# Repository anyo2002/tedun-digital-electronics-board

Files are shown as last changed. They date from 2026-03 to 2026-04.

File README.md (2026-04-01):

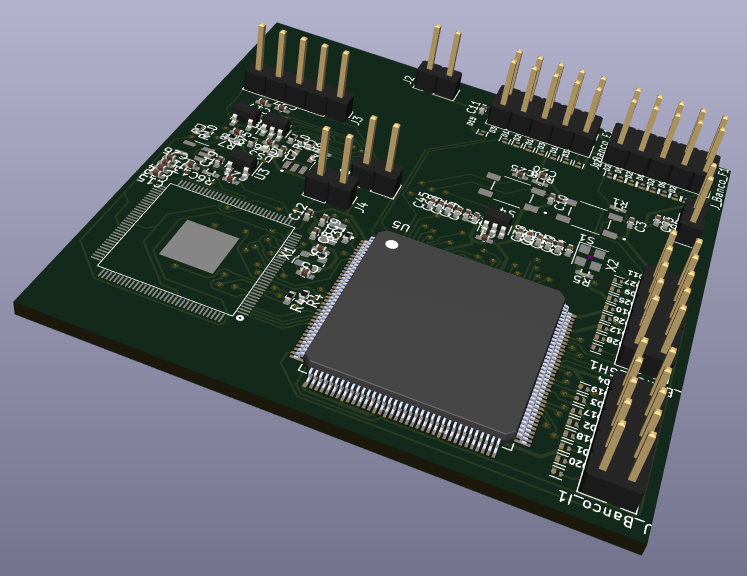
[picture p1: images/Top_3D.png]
Top 3D


# TEDUN - Digital Electronics Development Board

## 📌 Overview
The **TEDUN (Tarjeta de Electrónica Digital de la UNAL)** is an academic project developed as part of an Embedded Systems course in Electronic Engineering.

> ⚠️ Note: The project name does not represent an official product of UNAL. It only reflects the academic context in which it was developed.

This project consists of the design and implementation of a **custom development board** based on:
- A **F133A RISC-V processor**
- A **Trion T8Q144C3 FPGA**

The board enables hardware experimentation with multiple modules (Bluetooth, audio, infrared, etc.) using communication protocols such as **UART, I2S, SPI**, and **GPIO**.

---

## 🎯 Objectives
- Design a complete embedded development board
- Enable communication between a processor and an FPGA
- Support hardware testing using multiple digital interfaces
- Develop schematics and PCB using KiCad
- Implement FPGA programming using open-source tools

---

## ⚙️ Key Features

- Powered via **Micro-USB (~5V)**
- Boot via **SD card with Tina Linux**
- UART communication with a computer (via USB-UART converter)
- FPGA programming using **OpenOCD (JTAG)**
- Communication between F133A and FPGA via **UART or SPI**
- 32 GPIO pins organized in **4 banks (3.3V + 5V output)**

---

## 🏗️ System Architecture

The system integrates:
- F133A processor (RISC-V)
- Trion T8 FPGA
- SD card storage
- Multiple communication interfaces

### Interfaces

#### 🔹 JTAG
Used to program the FPGA through OpenOCD running on the F133A.

#### 🔹 SD Card
Stores:
- Tina Linux OS
- Boot partitions
- Drivers and applications
- FPGA configuration files

#### 🔹 UART & I2S
- UART for communication with PC and FPGA
- I2S for audio/data transmission

#### 🔹 GPIO
- 32 configurable pins
- Used for hardware testing and module integration

---

## 🧩 Block Diagram

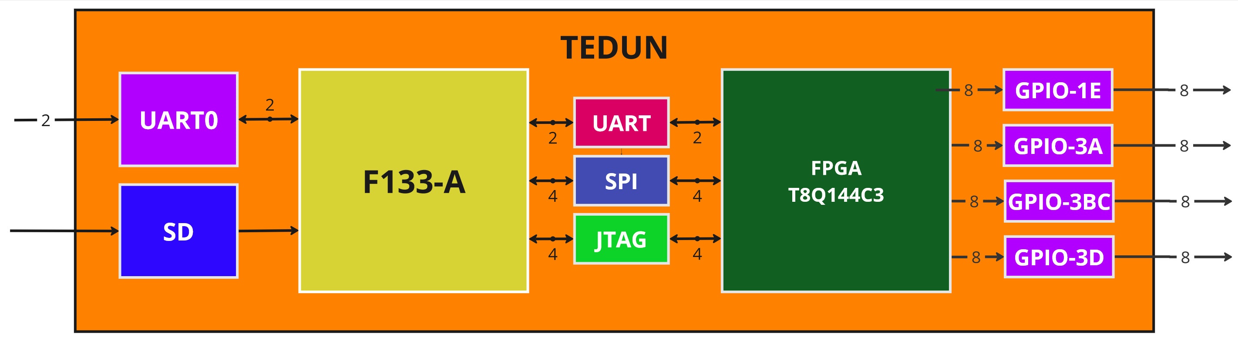
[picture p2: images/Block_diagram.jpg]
Block Diagram


---

## 🔌 Interface Design

To validate the system, an **LctechPi board (F133A-based)** was used for testing.

Key points:
- Tina Linux was configured and deployed
- Required system packages were installed
- WiFi was tested but not included (cost optimization)

### Tool Selection

Two tools were evaluated:

#### ❌ openFPGALoader
- Supports Trion FPGA
- Limited to memory-based programming (Flash)
- ❌ Not suitable for JTAG-based programming via F133A

#### ✅ OpenOCD
- Open-source
- Supports JTAG
- Compatible with Trion FPGA
- ✔️ Selected solution

---

## 🧪 FPGA Programming with OpenOCD

OpenOCD was compiled for RISC-V and deployed on the board.

### Setup Steps:
1. Compile OpenOCD from source:
   https://github.com/riscv/riscv-openocd

2. Copy binary to:
/bin/

3. Copy scripts to:
/usr/local/share/openocd/scripts

4. Create configuration file:
openocd.cfg

### Example Configuration (JTAG via GPIO)

```bash
adapter driver sysfsgpio
transport select jtag
sysfsgpio jtag_nums 2 3 1 4

set CHIPNAME fpga_trion
source [find fpga/efinix_trion.cfg]

init
pld load fpga_trion.pld GPIO_demo.bit
```

## 🛠️ Hardware Design

The hardware design is based on:

- MangoPi (F133A reference)

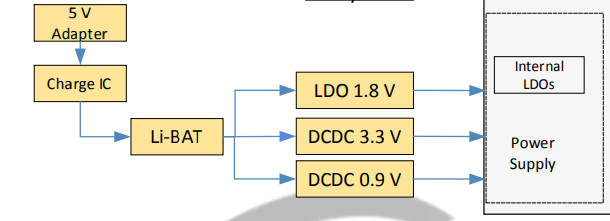
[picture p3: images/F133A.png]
Power Supply


- LctechPi board

- Trion T8 FPGA reference boards

## 🔋 Power Supply

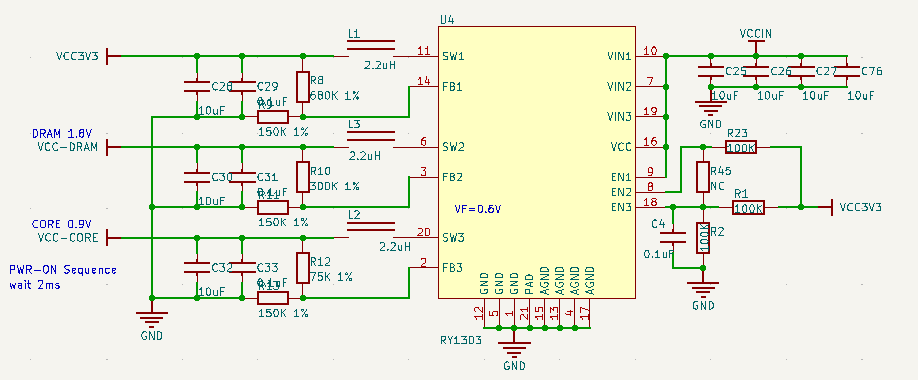
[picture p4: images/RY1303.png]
RY1303


- Input: Micro-USB (5V)
- Regulation using:
  - AMS1117 (instead of RY1303 from the MangoPi board)
  - Multiple LDO regulators

## Voltage Levels:
- 3.3V → I/O, GPIO, oscillator

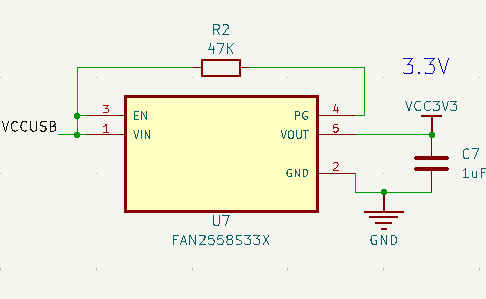
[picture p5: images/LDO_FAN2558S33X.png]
FAN2558S33X


- 1.8V → DRAM

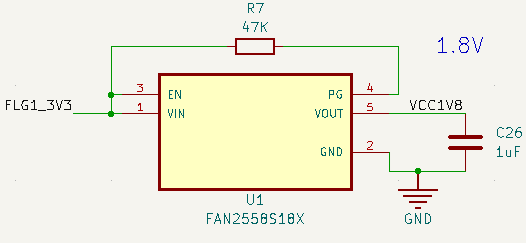
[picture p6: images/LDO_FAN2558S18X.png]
FAN2558S18X


- 2.8V → Communication block (PE)

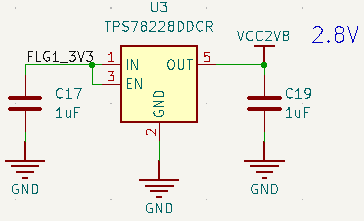
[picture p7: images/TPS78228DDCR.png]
TPS78228DDCR


- 1.2V → FPGA core

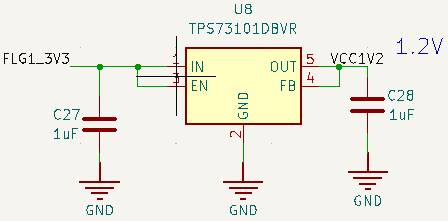
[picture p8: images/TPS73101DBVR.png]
TPS73101DBVR


- 0.9V → Processor core

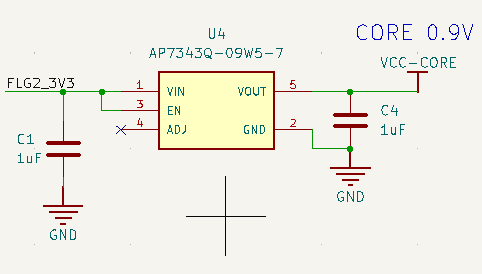
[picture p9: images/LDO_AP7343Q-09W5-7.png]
AP7343Q-09W5-7


## ⚡ Power Sequencing

Implemented using:
- LM3880 power sequencer

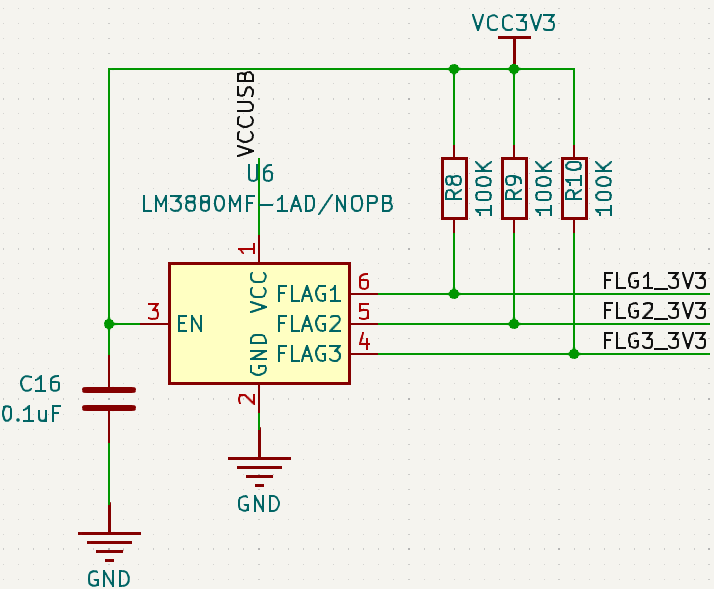
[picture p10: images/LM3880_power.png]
LM3880


Sequence: 
1. Enable FPGA + DRAM + PE
2. Enable processor core (0.9V)
3. Enable FPGA I/O

## 💾 SD Card
- Used for booting Tina Linux
- Based on MangoPi reference design

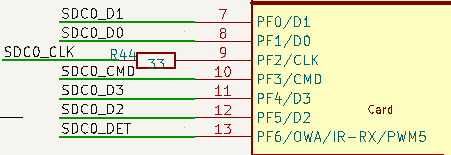
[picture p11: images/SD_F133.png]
SD F133


- Direct connection to F133A

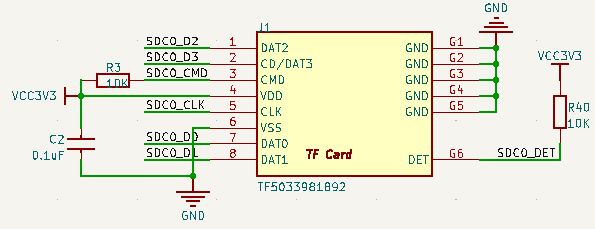
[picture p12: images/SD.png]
SD Module


## 🧠 F133A Connections

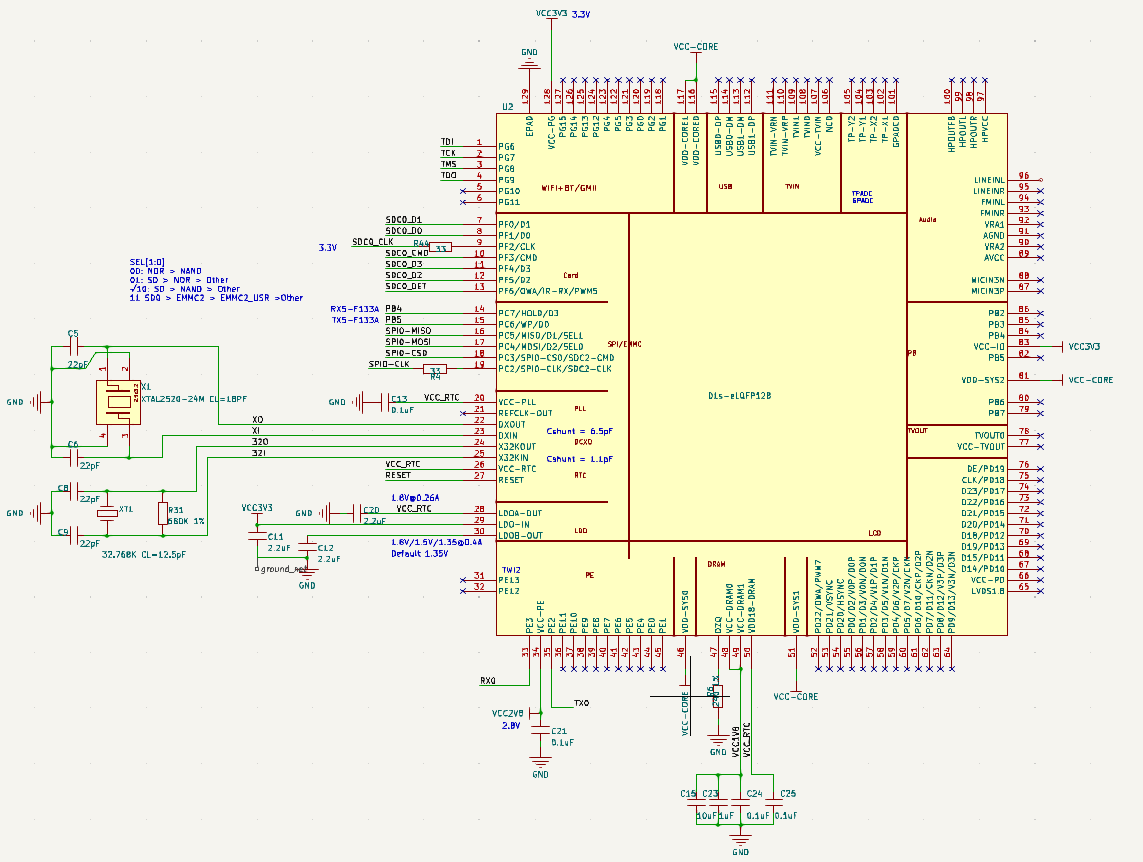
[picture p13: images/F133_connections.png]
F133 Connections


- JTAG → PG6–PG9
- UART0 → PE2 / PE3
- UART → PC6 / PC7
- SD → PF0–PF6
- SPI → PC2–PC7

## 🔲 FPGA (Trion T8)

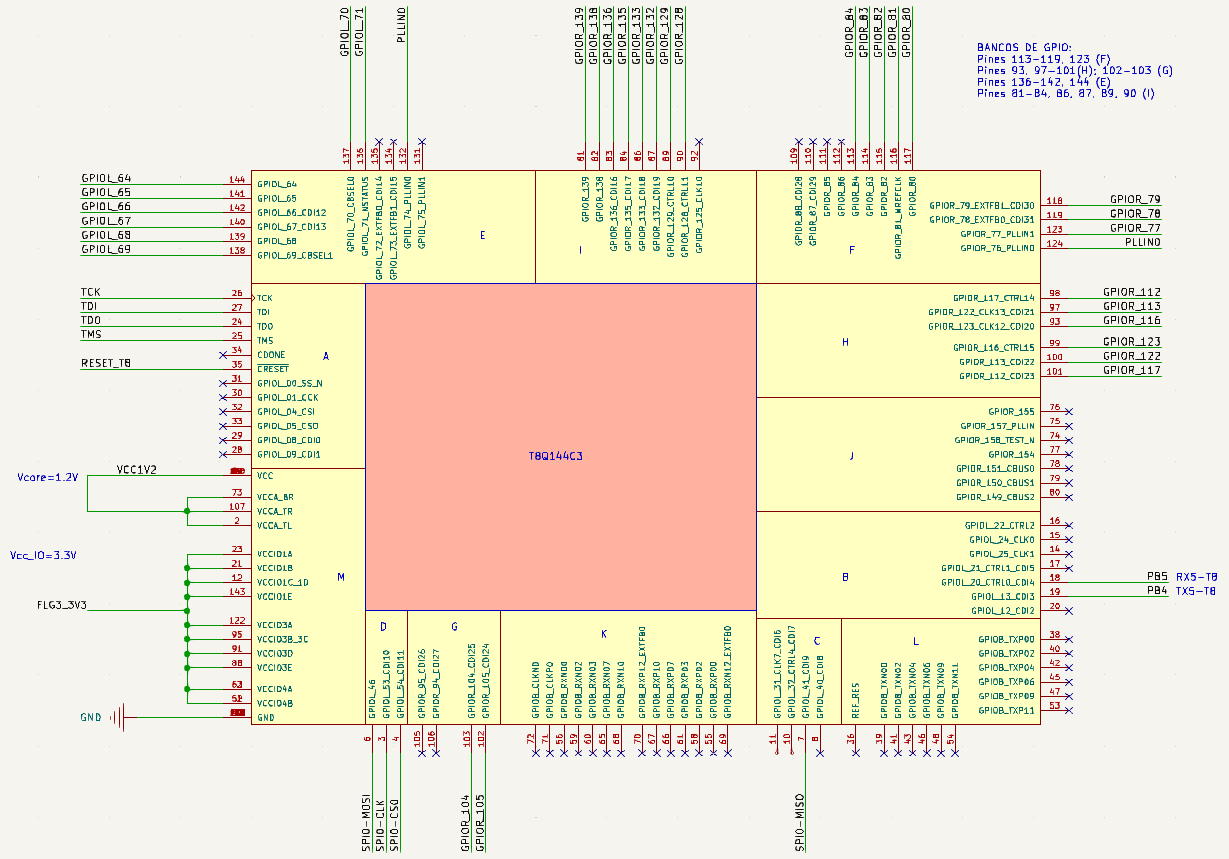
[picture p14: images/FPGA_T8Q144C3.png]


- 13 banks available
- Selected banks: 1A, 3A, 3BC, 3D
- Supports:
  - JTAG programming
  - SPI & UART communication
  - GPIO expansion

## 🔌 GPIO

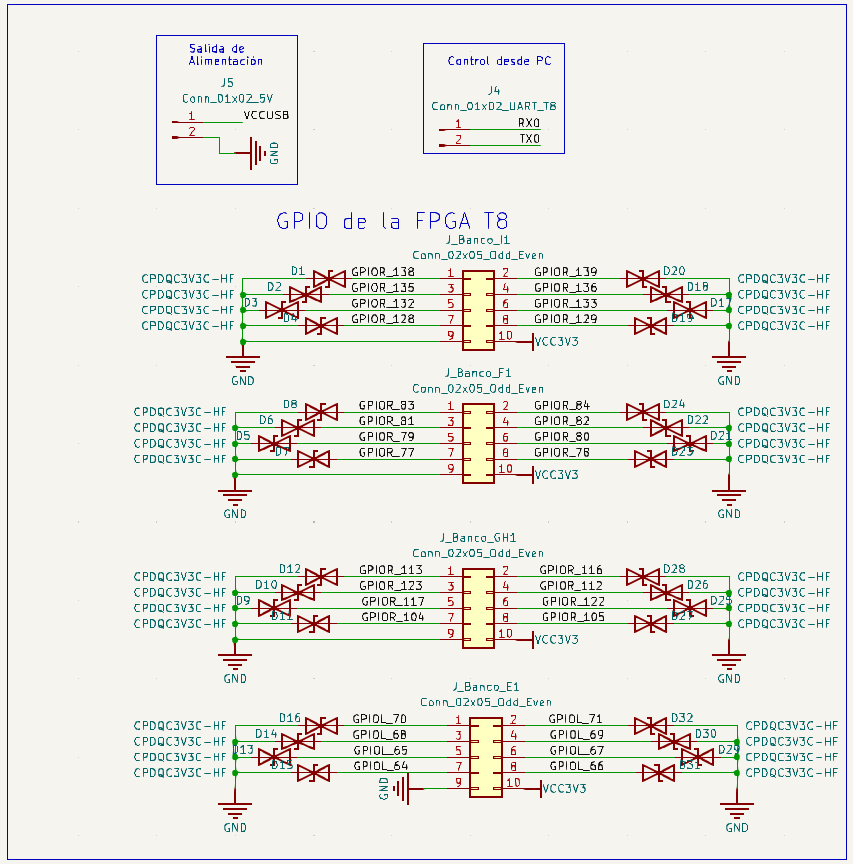
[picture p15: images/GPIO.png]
GPIO


- 32 GPIO pins (4 banks × 8 pins)
- Each bank includes:
  - 3.3V output
  - GND
- Additional:
  - 5V output
  - UART interface
## ⏱️ Oscillators
- FPGA: 25 MHz oscillator

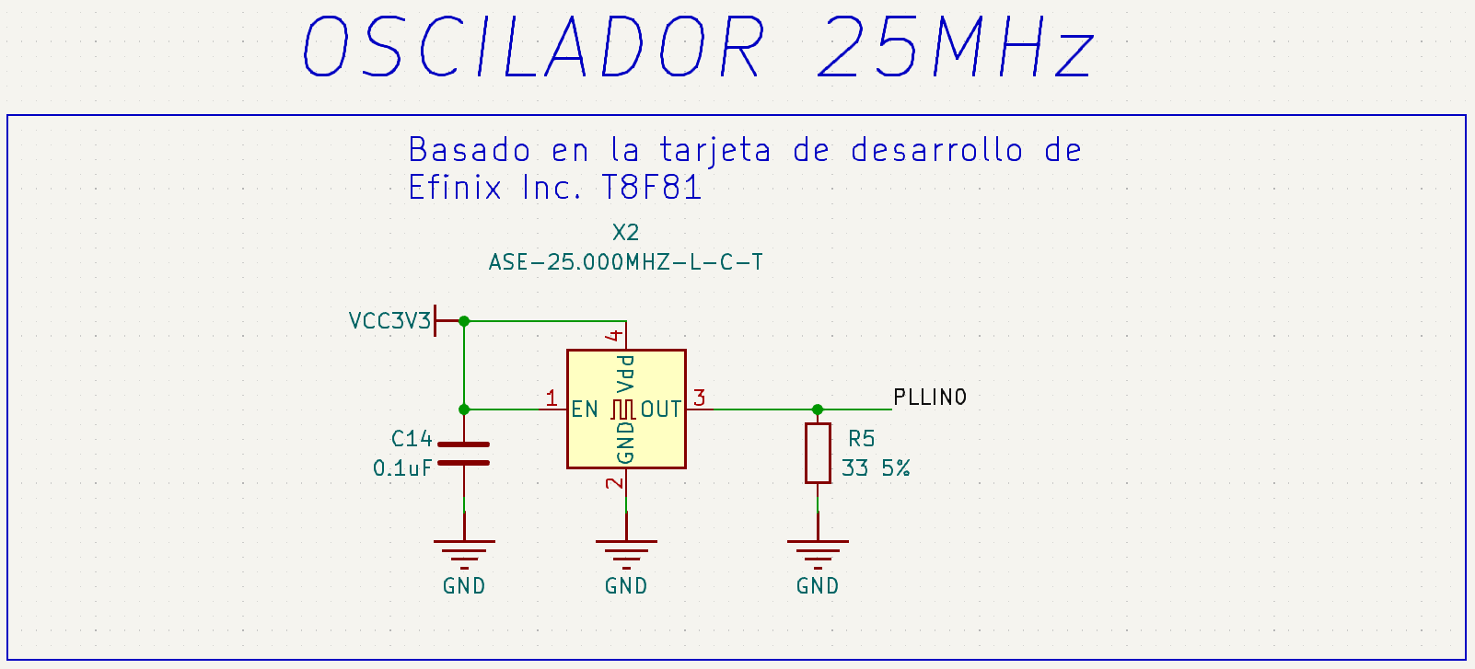
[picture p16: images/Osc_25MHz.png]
Oscillator 25MHz


- Processor: MangoPi reference oscillator

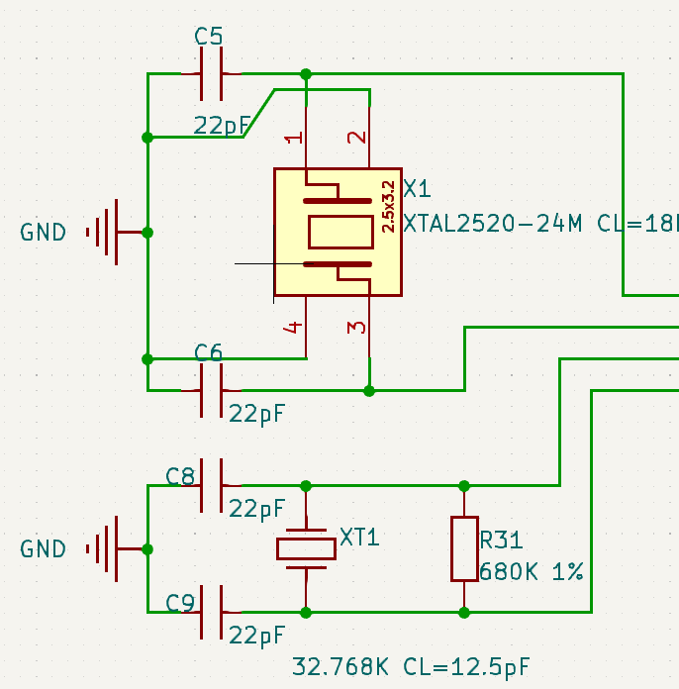
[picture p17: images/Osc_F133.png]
Oscillator F133


## 🧾 PCB Design

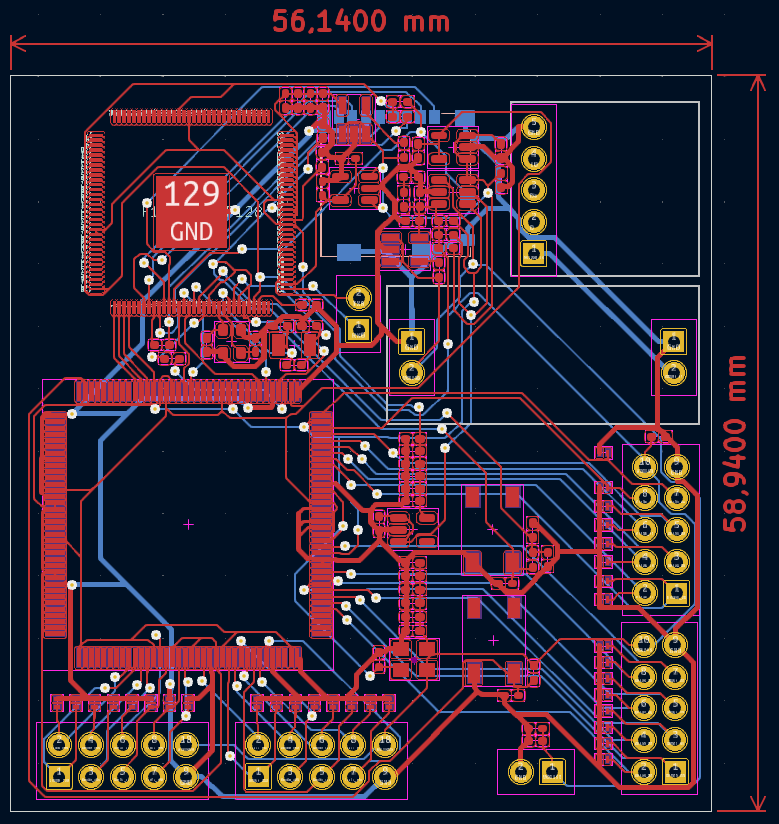
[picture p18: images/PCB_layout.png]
PCB layout


Designed in KiCad:
- Compact layout
- Optimized routing
- 3D visualization available

Top 3D

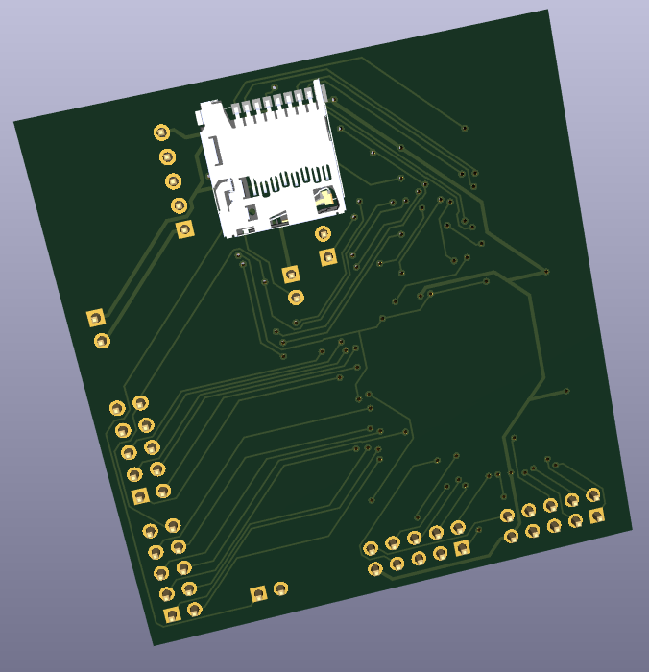
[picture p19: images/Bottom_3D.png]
Bottom 3D


## 📍 Pinout
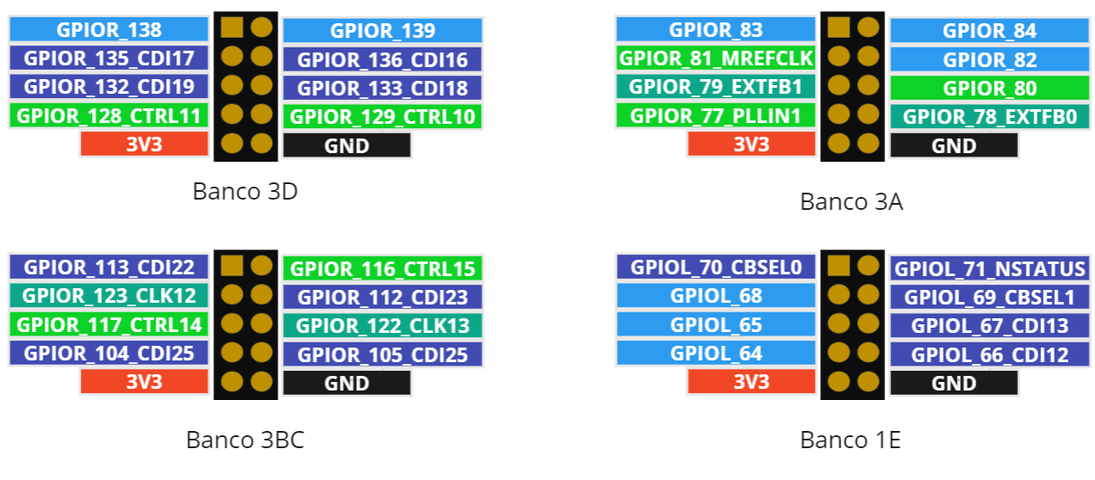
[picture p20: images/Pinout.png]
Pinout


Pin function

- 32 GPIO pins available
- Organized in 4 banks
- Flexible usage:
  - GPIO
  - Communication interfaces
  - Special FPGA functions

## 📚 References
- F133A Datasheet
- Trion T8 Datasheet
- MangoPi Schematics

## 🧰 Tools & Technologies
- KiCad (PCB design)
- OpenOCD (FPGA programming)
- Tina Linux
- RISC-V architecture
- Embedded Linux

## 🚀 Skills Demonstrated
- Embedded Systems Design
- FPGA Integration
- Hardware Architecture
- PCB Design (KiCad)
- Power Electronics (LDO, sequencing)
- Communication Protocols (UART, SPI, I2S, JTAG)

## 👤 Authors

- Angel RUIZ
- Santiago DIAZ
- Daniel CELY

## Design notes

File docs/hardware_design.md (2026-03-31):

# Hardware Design

## Power Supply

The power supply design of the TEDUN board is based on reference schematics from existing boards using the F133A processor.

### Power Supply Design

The system is powered through a **Micro-USB connector**, providing approximately 5V. However, measurements showed that the input voltage can vary between **6V and 6.7V**, making voltage regulation essential.

To ensure stable operation, the design includes:

- An **AMS1117 voltage regulator** to stabilize the input voltage to 5V
- Multiple **Low Dropout Regulators (LDOs)** to generate required voltage levels

### Voltage Levels

The system requires multiple voltage domains:

- **3.3V** → GPIO, I/O, oscillator, and internal LDO supply
- **1.8V** → DRAM power supply
- **2.8V** → Processor communication block (PE)
- **1.2V** → FPGA core voltage (within recommended range 1.15V–1.25V)
- **0.9V** → Processor core (F133A)

Each voltage rail includes **parallel capacitors** for stability and noise reduction.

### Components Used

- AMS1117 (5V regulation, instead of RY1303 from the MangoPi board)
- FAN2558S33X (3.3V)
- FAN2558S18X (1.8V)
- TPS78228DDCR (2.8V)
- TPS73101DBVR (1.2V)
- AP7343Q-09W5-7 (0.9V)

---

## Power Sequencing

Proper power sequencing is critical when integrating both the **F133A processor** and the **Trion T8 FPGA**, as each component has specific startup requirements.

To ensure a safe and correct startup sequence, the design uses the:

- **LM3880 Power Sequencer**

### Sequence Description

The power-up sequence is controlled using three signals:

1. **FLG1_3V3**
   - Activates first
   - Powers:
     - FPGA core (1.2V)
     - DRAM (1.8V)
     - Processor communication block (2.8V)

2. **FLG2_3V3**
   - Activates second
   - Powers:
     - Processor core (0.9V)

3. **FLG3_3V3**
   - Activates last
   - Powers:
     - FPGA I/O (VCCIO)

This sequence ensures compliance with both **F133A** and **FPGA T8** requirements.

> Note: No specific power-down sequence is required.

---

## FPGA Design (Trion T8)

The selected FPGA is the **Trion T8Q144C3**, which provides multiple configurable I/O banks and dedicated functional pins.

### Key Features

- 13 available banks
- Multiple pin functionalities:
  - Configuration
  - GPIO
  - LVDS
  - JTAG
  - Power

### Design Choices

Based on the FPGA packaging and datasheet analysis, the following banks were selected for GPIO usage:

- **Bank 1A**
- **Bank 3A**
- **Bank 3BC**
- **Bank 3D**

### Implemented Connections

- **JTAG pins** → Used for FPGA programming
- **SPI interface (4 pins)** → Communication with F133A
- **UART interface (2 pins)** → Communication with F133A
- **32 GPIO pins** → External hardware interaction
- **Clock input (CLK)** → External oscillator
- **Reset and configuration pins**

This configuration allows flexible use of the FPGA for multiple hardware experiments.

---

## PCB Design

After defining the schematics, the PCB layout was designed using **KiCad**.

### Design Goals

- Compact board size
- Optimized routing between components
- Clear separation of power and signal paths
- Reliable connections between processor and FPGA

### Features

- Dedicated power planes
- Organized GPIO pin headers

### Outputs

The final design includes:

- Complete schematic (Files in the [Hardware](../hardware/) folder)

Pinout
Pinout functions

- PCB layout

PCB layout

- 3D visualization of the board

Top 3D
Botton 3D

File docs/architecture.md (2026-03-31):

# Architecture

## Overview
The TEDUN board integrates a RISC-V processor (F133A) with a Trion T8 FPGA.

## Interfaces

### JTAG
Used for FPGA programming via OpenOCD.

### SD Card
Used for booting Tina Linux and storing FPGA bitstreams.

### UART & I2S
Used for communication between:
- PC ↔ F133A
- F133A ↔ FPGA

### GPIO
32 configurable pins used for hardware experimentation.

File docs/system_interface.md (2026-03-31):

# System Interface Design

## Overview

During the development of the TEDUN project, an **LctechPi board (F133A-based)** was used as a validation platform to test and define the communication interface between the processor and the FPGA.

This approach allowed:
- Early validation of hardware communication
- Definition of pin connections before PCB design
- Testing of FPGA programming workflows

---

## 🧪 Development Platform

The LctechPi board was used to:

- Configure and run **Tina Linux**
- Install required system packages
- Validate communication interfaces

A WiFi module was also tested successfully; however, it was **not included in the final design** due to:
- Lack of necessity for FPGA programming
- Additional hardware cost

---

## 🔌 Communication Architecture

The main role of the system interface is to enable communication between:

- **Computer ↔ F133A processor**
- **F133A processor ↔ FPGA (Trion T8)**

### Data Flow

1. The computer sends data via **UART (RX/TX pins)**
2. The F133A receives and processes the data
3. The processor forwards configuration data to the FPGA via:
   - **JTAG (primary method)**
   - Optional interfaces (SPI, UART)

This architecture allows the processor to act as an **intermediary controller** for FPGA configuration and communication.

---

## 🛠️ FPGA Programming Tool Selection

To program the FPGA, an open-source tool was required with the following characteristics:

- Compatibility with **Efinix Trion T8 FPGA**
- Support for **JTAG programming**
- Ability to run on an embedded Linux system (F133A)

### Evaluated Options

#### ❌ openFPGALoader
- Supports Trion FPGA family
- Primarily designed for **memory-based programming (Flash)**

Limitation:
- Does not support the required **JTAG-based programming via processor GPIO**

➡️ **Rejected for this project**

---

#### ✅ OpenOCD
- Open-source hardware debugging tool
- Supports:
  - Multiple JTAG interfaces
  - FPGA programming
  - Embedded Linux environments

Advantages:
- Compatible with **Trion T8 FPGA**
- Supports **GPIO-based JTAG implementation**
- Easily integrable with the F133A system

➡️ **Selected as the final solution**

---

## 🎯 Design Outcome

This interface design enables:

- Reliable communication between processor and FPGA
- FPGA programming directly from the embedded system
- Flexible experimentation with hardware modules
- A fully self-contained development board architecture

---

## 🚀 Key Takeaways

- Early prototyping with development boards reduces hardware risks
- Open-source tools provide flexibility and integration advantages
- JTAG over GPIO is a powerful method for embedded FPGA programming

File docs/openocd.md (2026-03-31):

# OpenOCD Configuration

## Overview

To configure and program the FPGA, **OpenOCD (Open On-Chip Debugger)** was used as the main tool.

Initial validation was performed using a *Nexys A7* board, where it was verified that the **sysfsgpio interface** combined with the **JTAG protocol** can successfully upload a `.bit` file to an FPGA.

---

## 🔧 Building OpenOCD for RISC-V

The first step is to compile OpenOCD with **RISC-V support** from source:

Repository:
https://github.com/riscv/riscv-openocd

The compilation is performed using the provided **cross-compilation scripts**, where the toolchain path must be configured.

This toolchain is obtained when generating the **Tina Linux image**:
https://github.com/mangopi-sbc/Tina-Linux

---

## 📦 Installation on the Board

After compilation:

- The OpenOCD binary is copied to:
/bin/

- The configuration scripts (`tcl` folder) are copied to:
/usr/local/share/openocd/scripts

This process is equivalent to installing OpenOCD on a standard Linux system.

---

## ⚙️ Configuration File

A configuration file named:
openocd.cfg

must be created in the scripts directory.

This file is executed every time the `openocd` command is run from the development board terminal.

---

## 🔌 JTAG Configuration via GPIO

To configure JTAG using the **GPIO pins of the F133A**, the following setup was tested and validated:

### Example (Xilinx FPGA)

```bash
adapter driver sysfsgpio
transport select jtag

# GPIO mapping: tck tms tdi tdo
sysfsgpio jtag_nums 2 3 1 4

tcl_port disabled
telnet_port disabled

set CHIPNAME fpga_xilinx
source [find cpld/xilinx-xc7.cfg]

init
pld load fpga_xilinx.pld GPIO_demo.bit
```
## 🔄 Configuration for Trion T8 FPGA
To use the Efinix Trion T8 FPGA, the configuration must be modified as follows:

```bash
sysfsgpio jtag_nums 2 3 1 4

set CHIPNAME fpga_trion
source [find fpga/efinix_trion.cfg]

pld load fpga_trion.pld GPIO_demo.bit
```
## ⚠️ Design Considerations
Although OpenOCD allows flexible GPIO configuration for JTAG, this is not recommended in the final TEDUN board, since:
1. JTAG pins are already hardwired in the PCB
2. Manual reconfiguration could introduce inconsistencies

## 📁 Bitstream Loading
The FPGA configuration file must be a .bit file.

This file is generated using the Efinix development software (Efinity):
https://www.efinixinc.com/products-efinity.html

It can be replaced dynamically depending on the desired hardware functionality.

## 📚 Additional Resources
- OpenOCD FPGA documentation:
https://openocd.org/doc/html/PLD_002fFPGA-Commands.html

- JTAG interface documentation:
https://openocd.org/doc/html/Debug-Adapter-Hardware.html

## 🚀 Summary

This implementation demonstrates:

- Successful integration of OpenOCD in an embedded Linux system
- FPGA programming via JTAG using GPIO
- Cross-compilation for RISC-V architecture
- Compatibility with Efinix Trion FPGA devices

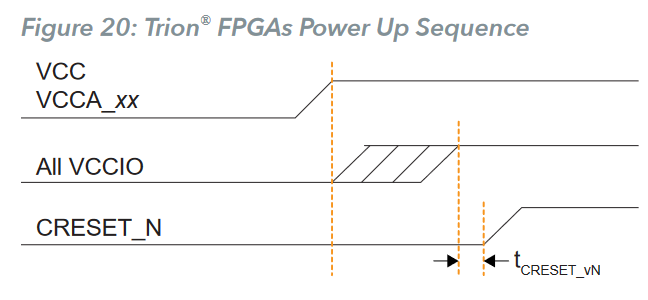
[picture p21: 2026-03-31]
images/Power_sequence_T8.png

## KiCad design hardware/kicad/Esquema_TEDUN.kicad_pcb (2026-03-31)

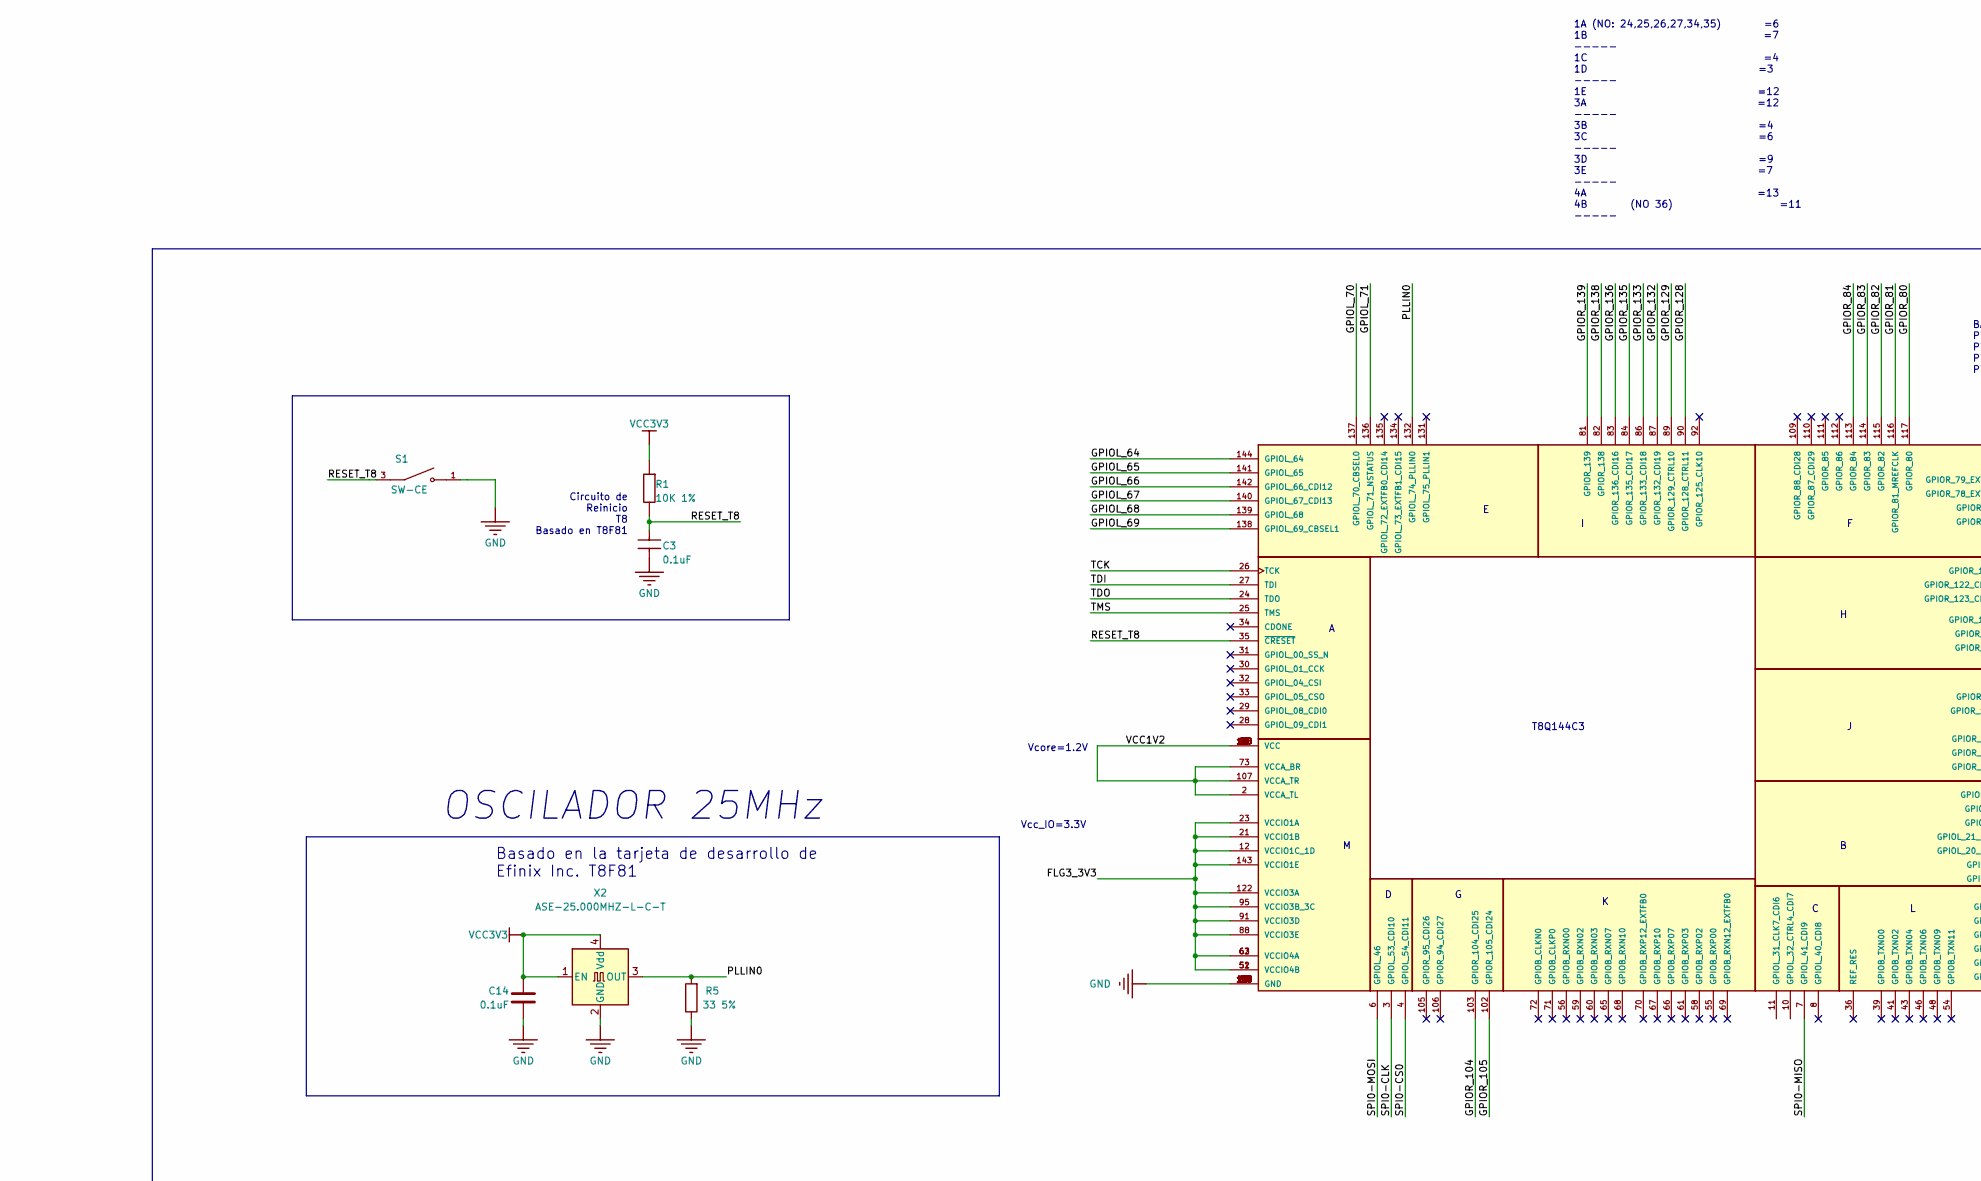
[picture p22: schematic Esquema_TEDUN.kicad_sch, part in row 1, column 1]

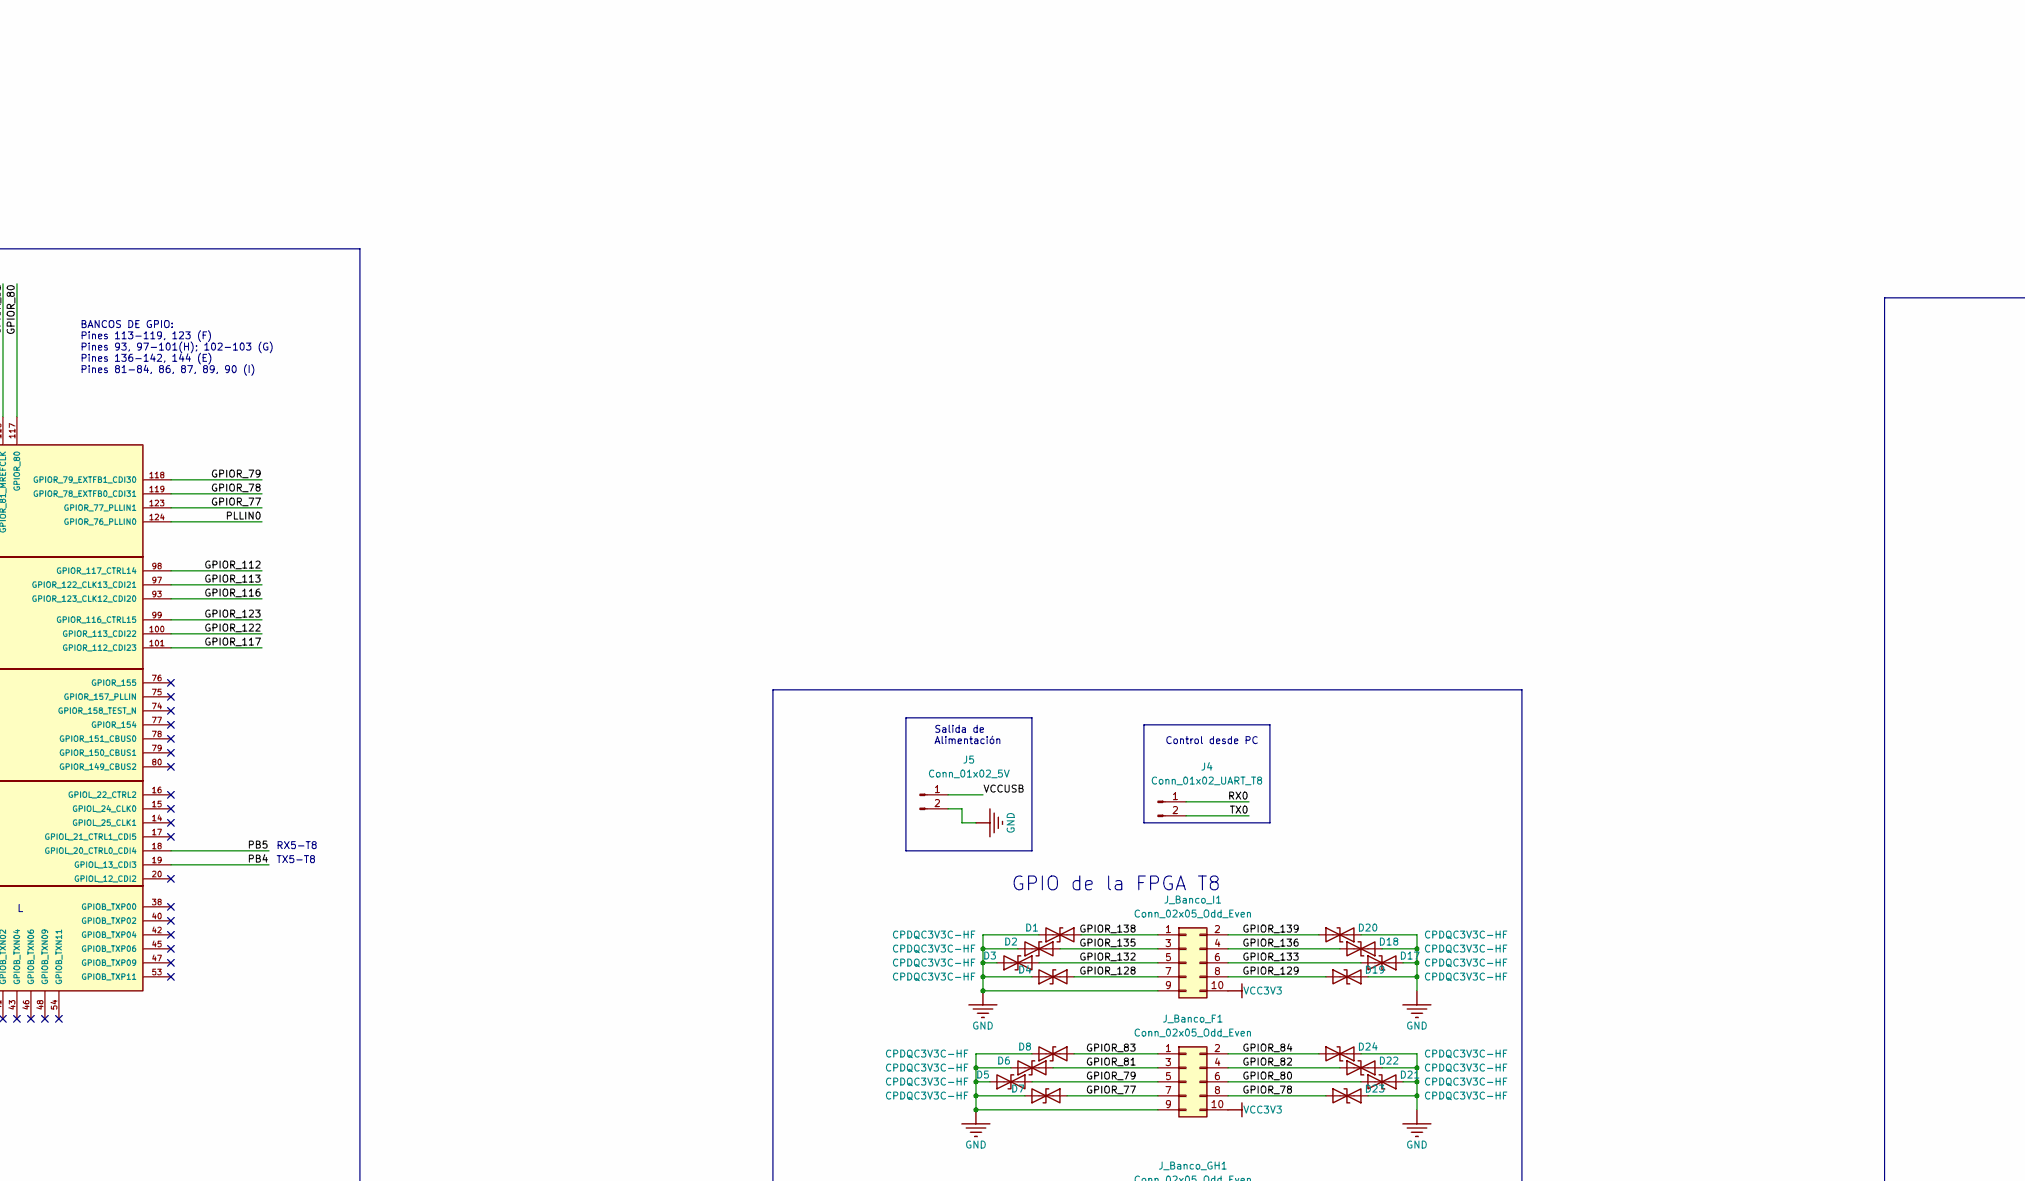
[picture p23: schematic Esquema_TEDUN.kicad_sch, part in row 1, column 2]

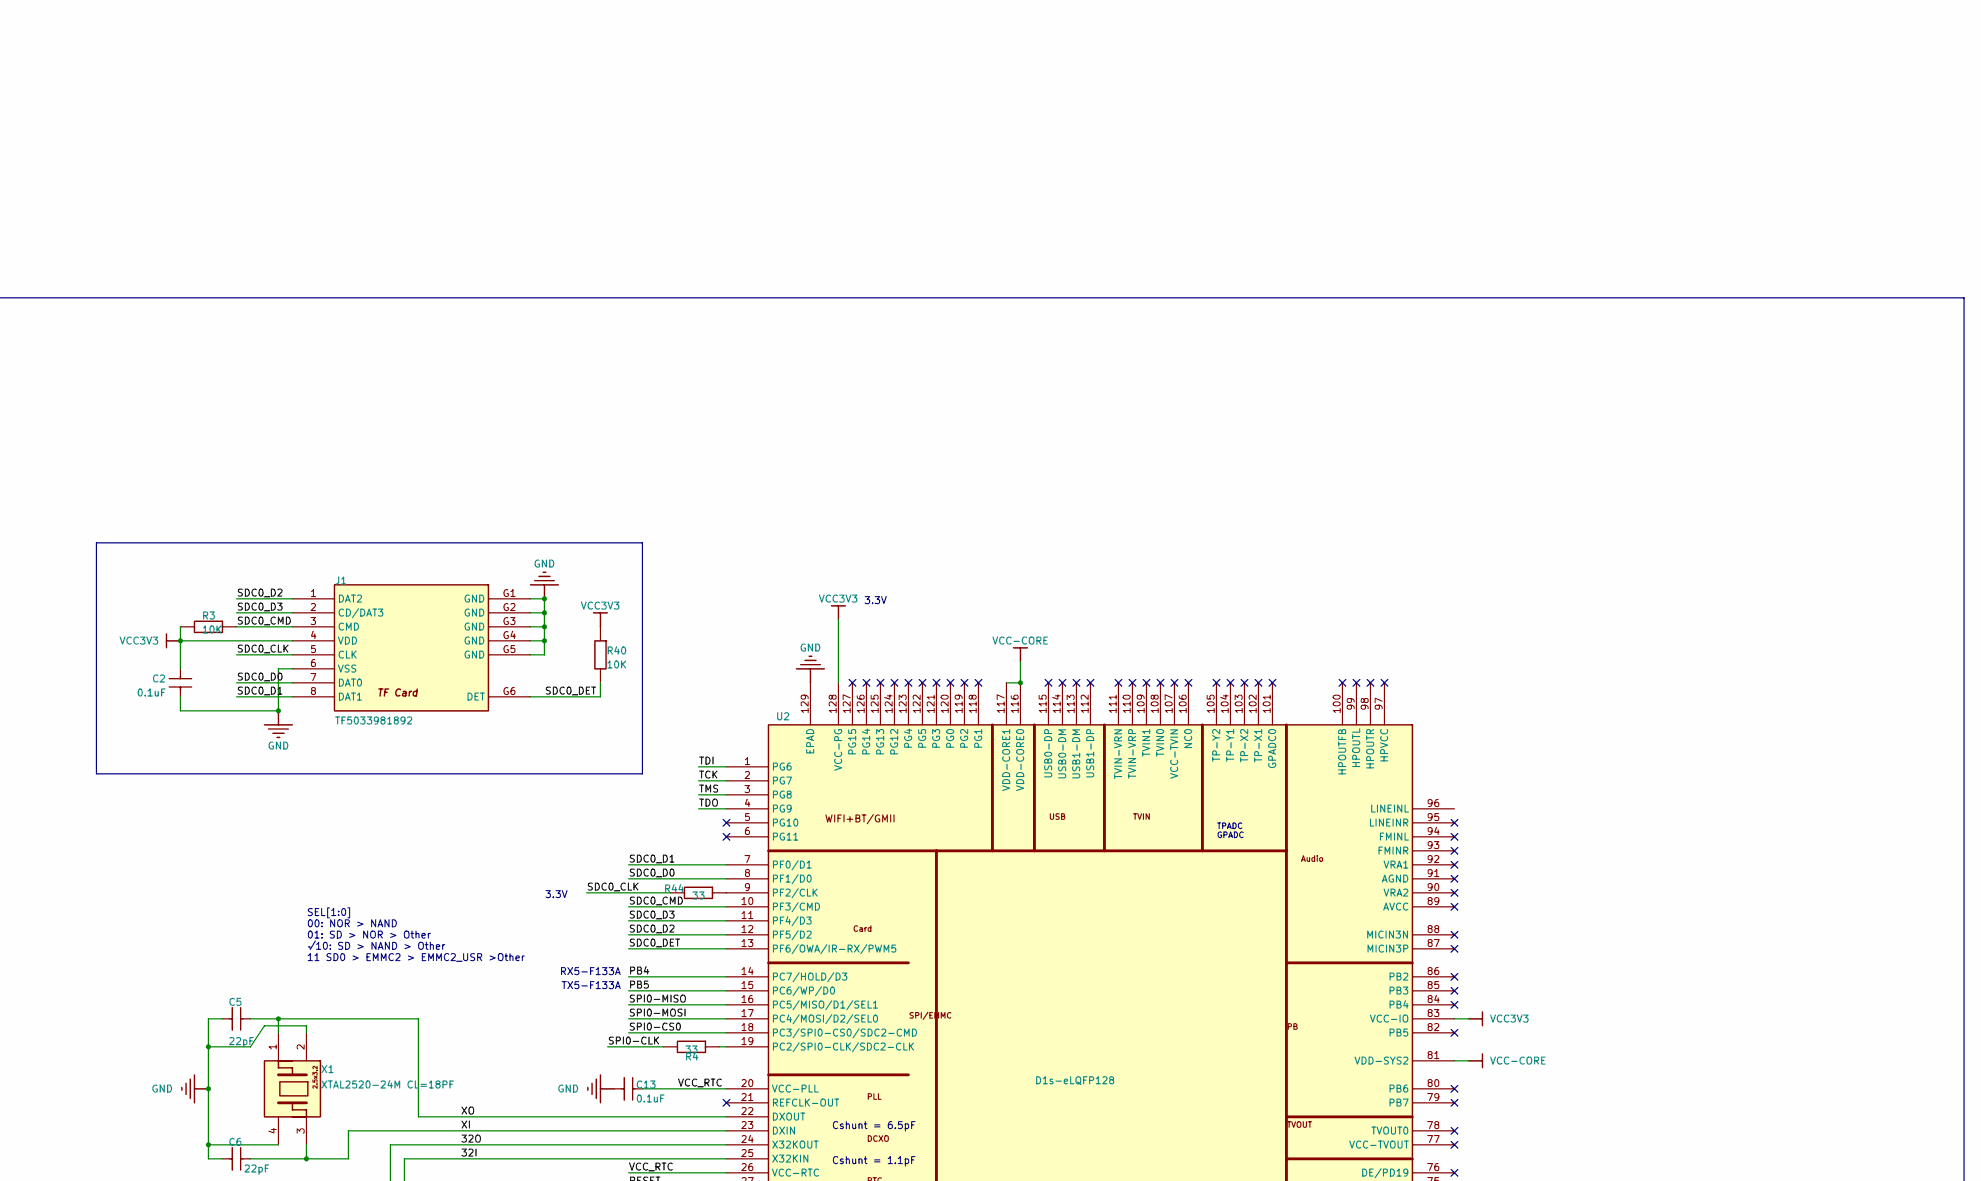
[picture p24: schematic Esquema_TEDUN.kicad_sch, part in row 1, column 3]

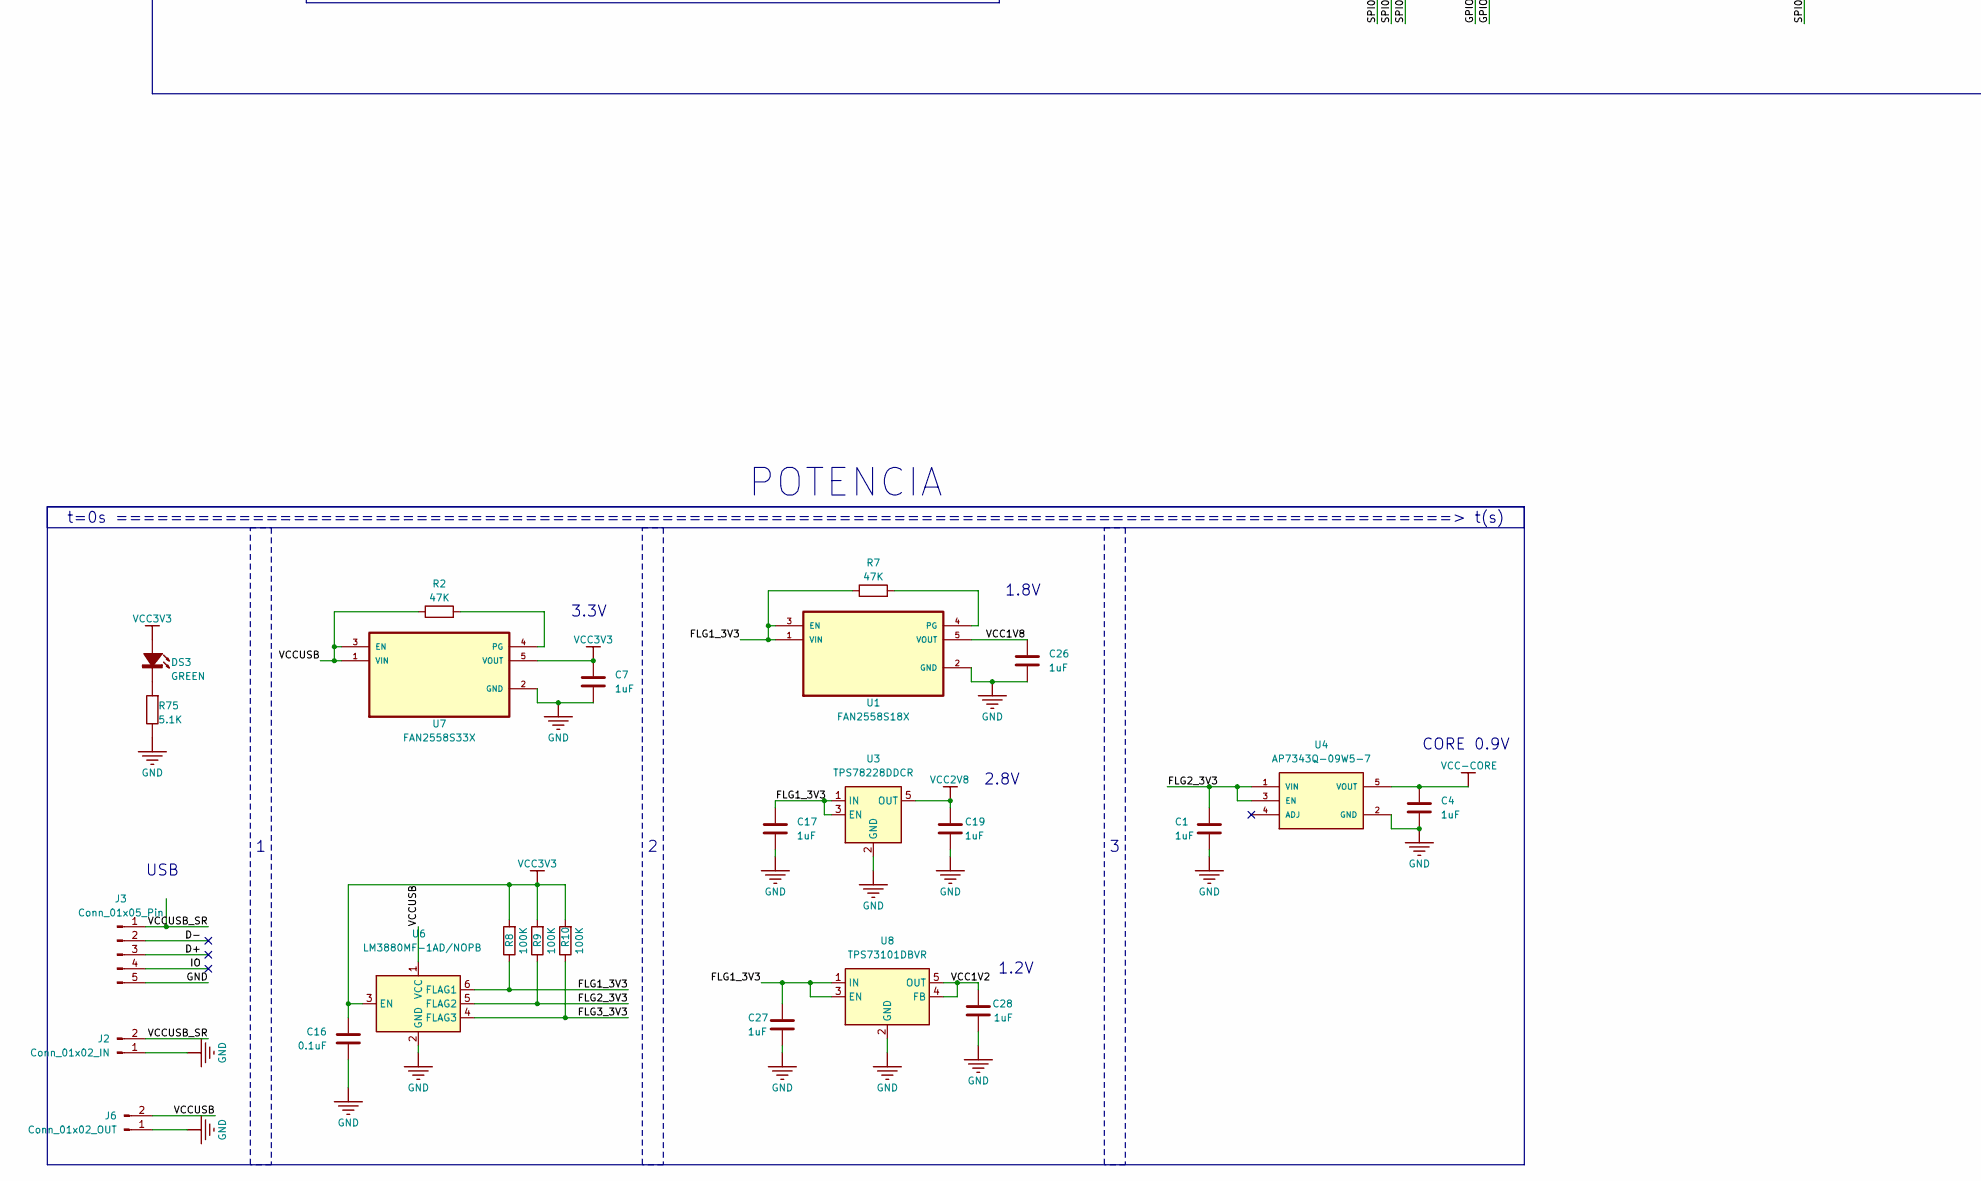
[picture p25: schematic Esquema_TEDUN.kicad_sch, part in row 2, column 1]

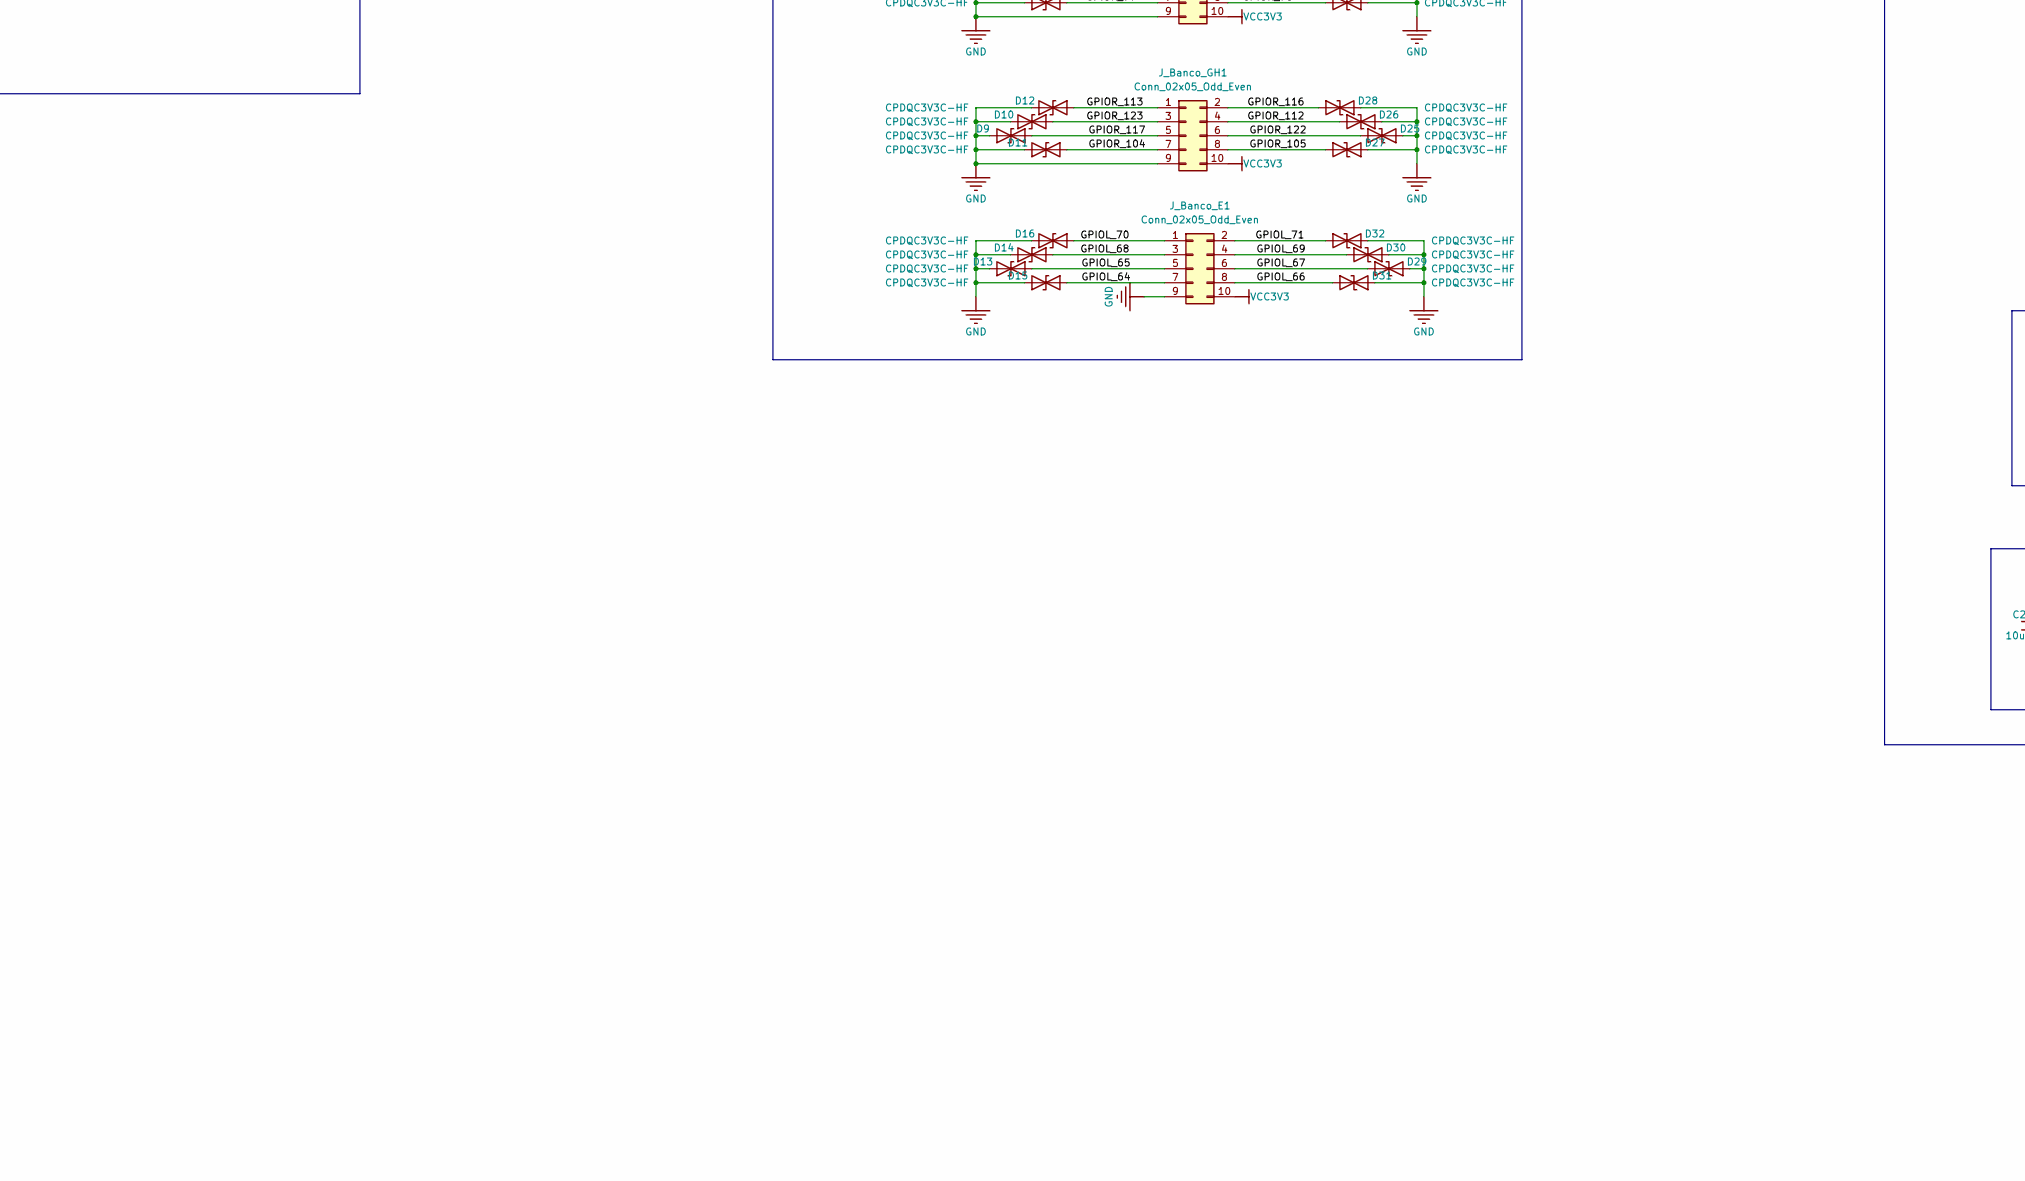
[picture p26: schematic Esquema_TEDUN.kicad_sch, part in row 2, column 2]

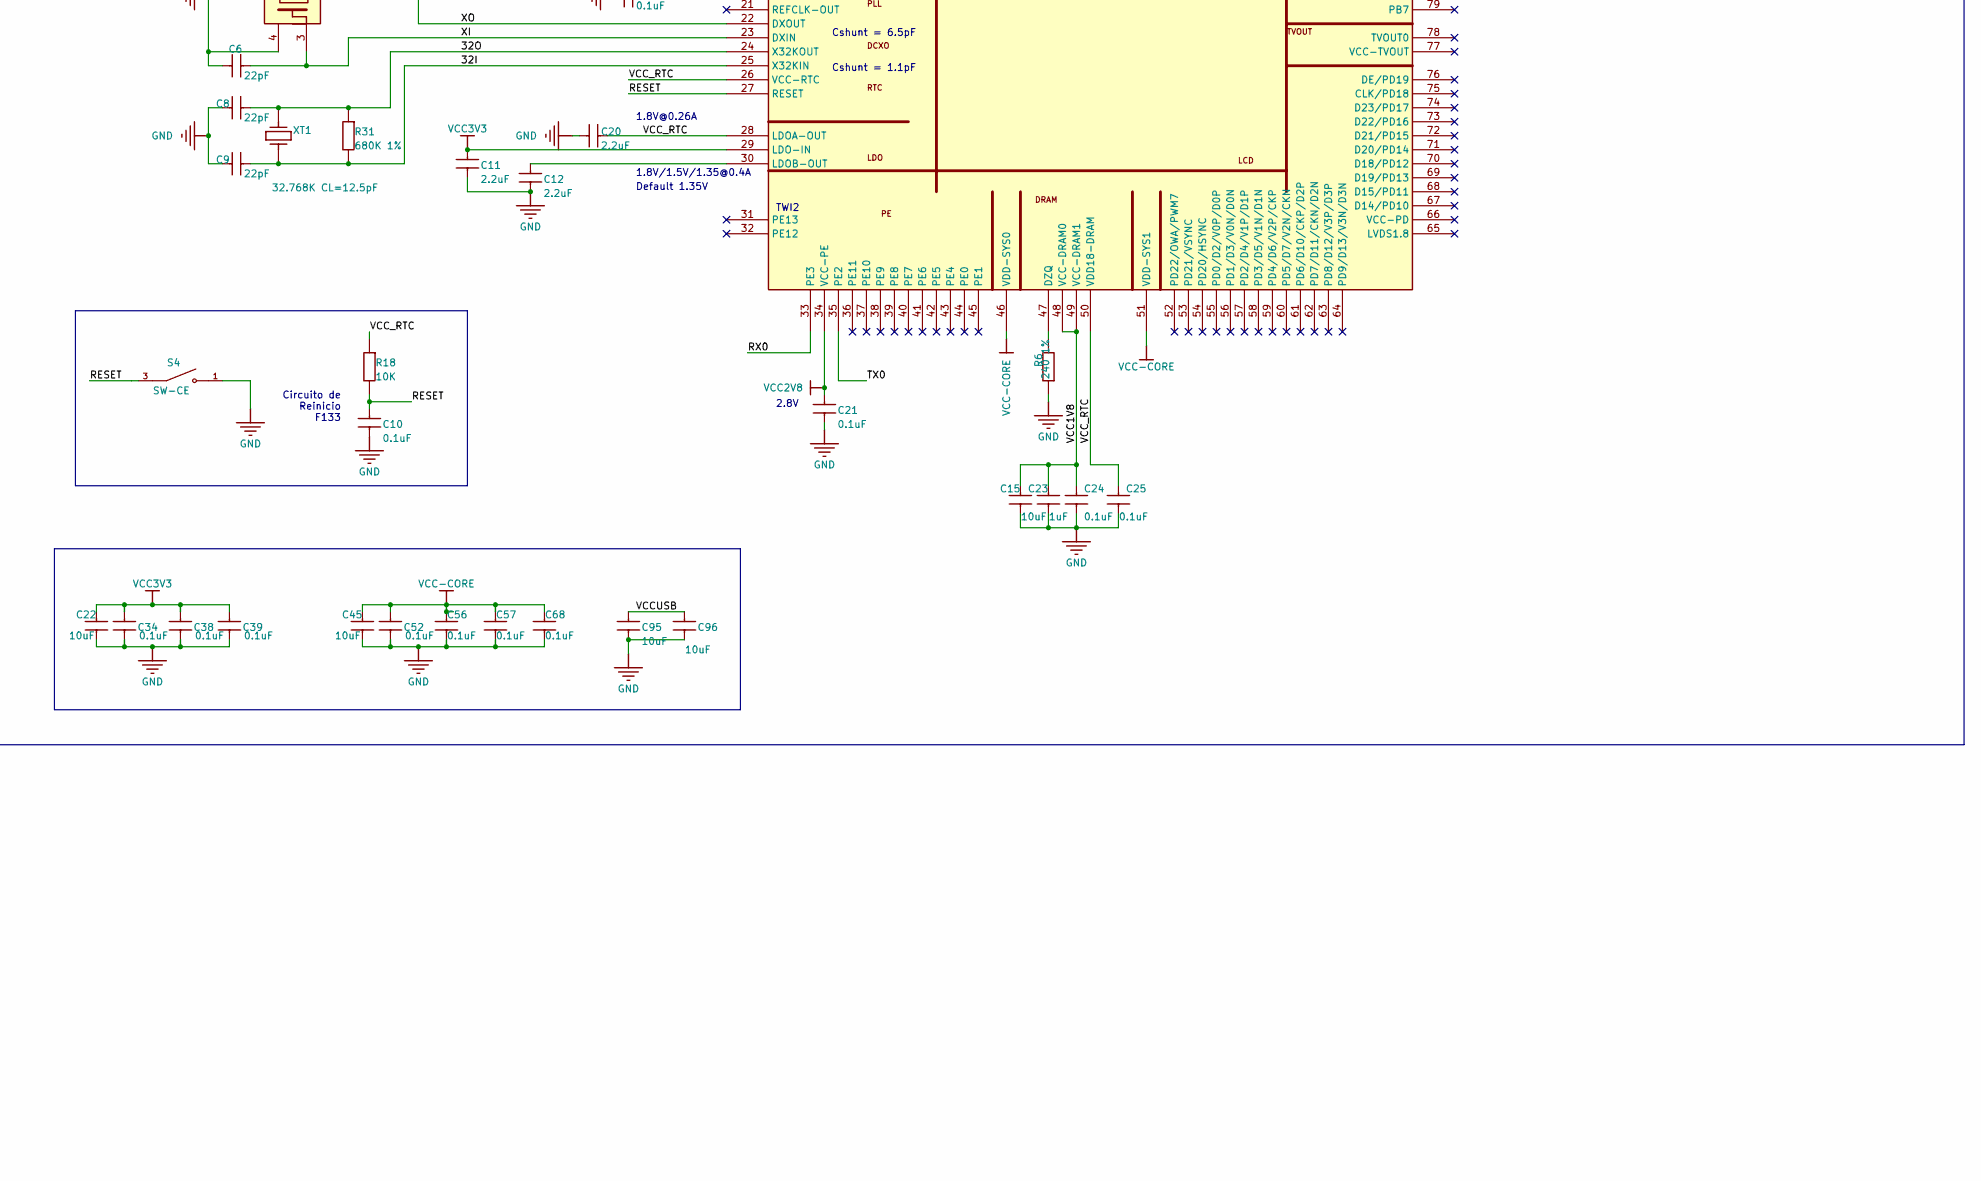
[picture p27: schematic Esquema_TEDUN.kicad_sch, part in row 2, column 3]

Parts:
C1, C4, C7, C17, C19, C23, C26, C27, C28: 1uF; C_0402_1005Metric_Pad0.74x0.62mm_HandSolder
C2, C3, C10, C13, C14, C16, C21, C24, C25, C34, C38, C39, C52, C56, C57, C68: 0.1uF; C_0402_1005Metric_Pad0.74x0.62mm_HandSolder
C5, C6, C8, C9: 22pF; C_0402_1005Metric_Pad0.74x0.62mm_HandSolder
C11, C12, C20: 2.2uF; C_0402_1005Metric_Pad0.74x0.62mm_HandSolder
C15, C22, C45, C95, C96: 10uF; C_0402_1005Metric_Pad0.74x0.62mm_HandSolder
D1, D2, D3, D4, D5, D6, D7, D8, D9, D10, D11, D12, D13, D14, D15, D16, D17, D18, D19, D20, D21, D22, D23, D24, D25, D26, D27, D28, D29, D30, D31, D32: CPDQC3V3C-HF; DIODFN100X60X43-2N
DS3: GREEN; LED_0402_1005Metric_Pad0.77x0.64mm_HandSolder
J1: TF5033981892; TFCARD-1040310811
J2: Conn_01x02_IN; PinHeader_1x02_P2.54mm_Vertical
J3: Conn_01x05_Pin; PinHeader_1x05_P2.54mm_Vertical
J4: Conn_01x02_UART_T8; PinHeader_1x02_P2.54mm_Vertical
J5: Conn_01x02_5V; PinHeader_1x02_P2.54mm_Vertical
J6: Conn_01x02_OUT; PinHeader_1x02_P2.54mm_Vertical
J_Banco_E1: Conn_02x05_Odd_Even; PinHeader_2x05_P2.54mm_Vertical
J_Banco_F1: Conn_02x05_Odd_Even; PinHeader_2x05_P2.54mm_Vertical
J_Banco_GH1: Conn_02x05_Odd_Even; PinHeader_2x05_P2.54mm_Vertical
J_Banco_I1: Conn_02x05_Odd_Even; PinHeader_2x05_P2.54mm_Vertical
R1: 10K 1%; R_0402_1005Metric_Pad0.72x0.64mm_HandSolder
R2, R7: 47K; R_0402_1005Metric_Pad0.72x0.64mm_HandSolder
R3, R18, R40: 10K; R_0402_1005Metric_Pad0.72x0.64mm_HandSolder
R4, R44: 33; R_0402_1005Metric_Pad0.72x0.64mm_HandSolder
R5: 33 5%; R_0402_1005Metric_Pad0.72x0.64mm_HandSolder
R6: 240 1%; R_0402_1005Metric_Pad0.72x0.64mm_HandSolder
R8, R9, R10: 100K; R_0402_1005Metric_Pad0.72x0.64mm_HandSolder
R31: 680K 1%; R_0402_1005Metric_Pad0.72x0.64mm_HandSolder
R75: 5.1K; R_0402_1005Metric_Pad0.72x0.64mm_HandSolder
S1, S4: SW-CE; SW_PTS_647_SM38_SMTR2_LFS; PARTREV 11 Jun 19; DigiKey_Part_Number PTS647SM38SMTR2LFSTR-ND
U1: FAN2558S18X; FAN2558S33X
U2: D1s-eLQFP128; F133A_QFP129
U3: TPS78228DDCR; SOT-23-5
U4: AP7343Q-09W5-7; SOT-23-5
U5: T8Q144C3; QFP50P2200X2200X160-144N; PARTREV V3.6
U6: LM3880MF-1AD/NOPB; SOT-23-6
U7: FAN2558S33X
U8: TPS73101DBVR; SOT-23-5
X1: XTAL2520-24M CL=18PF; Oscillator_SMD_ECS_2520MV-xxx-xx-4Pin_2.5x2.0mm
X2: ASE-25.000MHZ-L-C-T; Oscillator_SMD_Abracon_ASE-4Pin_3.2x2.5mm
XT1: 32.768K CL=12.5pF; Y3215

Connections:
/32I: C9.1, R31.2, U2.25 (X32KIN), XT1.1
/32O: C8.1, R31.1, U2.24 (X32KOUT), XT1.2
/D+: J3.3
/D-: J3.2
/FLG1_3V3: C17.2, C27.1, R7.1, R8.1, U1.1 (VIN), U1.3 (EN), U3.1 (IN), U3.3 (EN), U6.6 (FLAG1), U8.1 (IN), U8.3 (EN)
/FLG2_3V3: C1.1, R9.1, U4.1 (VIN), U4.3 (EN), U6.5 (FLAG2)
/FLG3_3V3: R10.1, U5.12 (VCCIO1C_1D), U5.21 (VCCIO1B), U5.23 (VCCIO1A), U5.51 (VCCIO4B), U5.52 (VCCIO4B), U5.62 (VCCIO4A), U5.63 (VCCIO4A), U5.88 (VCCIO3E), U5.91 (VCCIO3D), U5.95 (VCCIO3B_3C), U5.122 (VCCIO3A), U5.143 (VCCIO1E), U6.4 (FLAG3)
/GPIOL_64: D15.2 (A2), J_Banco_E1.7, U5.144 (GPIOL_64)
/GPIOL_65: D13.2 (A2), J_Banco_E1.5, U5.141 (GPIOL_65)
/GPIOL_66: D31.2 (A2), J_Banco_E1.8, U5.142 (GPIOL_66_CDI12)
/GPIOL_67: D29.2 (A2), J_Banco_E1.6, U5.140 (GPIOL_67_CDI13)
/GPIOL_68: D14.2 (A2), J_Banco_E1.3, U5.139 (GPIOL_68)
/GPIOL_69: D30.2 (A2), J_Banco_E1.4, U5.138 (GPIOL_69_CBSEL1)
/GPIOL_70: D16.2 (A2), J_Banco_E1.1, U5.137 (GPIOL_70_CBSEL0)
/GPIOL_71: D32.2 (A2), J_Banco_E1.2, U5.136 (GPIOL_71_NSTATUS)
/GPIOR_77: D7.2 (A2), J_Banco_F1.7, U5.123 (GPIOR_77_PLLIN1)
/GPIOR_78: D23.2 (A2), J_Banco_F1.8, U5.119 (GPIOR_78_EXTFB0_CDI31)
/GPIOR_79: D5.2 (A2), J_Banco_F1.5, U5.118 (GPIOR_79_EXTFB1_CDI30)
/GPIOR_80: D21.2 (A2), J_Banco_F1.6, U5.117 (GPIOR_80)
/GPIOR_81: D6.2 (A2), J_Banco_F1.3, U5.116 (GPIOR_81_MREFCLK)
/GPIOR_82: D22.2 (A2), J_Banco_F1.4, U5.115 (GPIOR_82)
/GPIOR_83: D8.2 (A2), J_Banco_F1.1, U5.114 (GPIOR_83)
/GPIOR_84: D24.2 (A2), J_Banco_F1.2, U5.113 (GPIOR_84)
/GPIOR_104: D11.2 (A2), J_Banco_GH1.7, U5.103 (GPIOR_104_CDI25)
/GPIOR_105: D27.2 (A2), J_Banco_GH1.8, U5.102 (GPIOR_105_CDI24)
/GPIOR_112: D26.2 (A2), J_Banco_GH1.4, U5.98 (GPIOR_117_CTRL14)
/GPIOR_113: D12.2 (A2), J_Banco_GH1.1, U5.97 (GPIOR_122_CLK13_CDI21)
/GPIOR_116: D28.2 (A2), J_Banco_GH1.2, U5.93 (GPIOR_123_CLK12_CDI20)
/GPIOR_117: D9.2 (A2), J_Banco_GH1.5, U5.101 (GPIOR_112_CDI23)
/GPIOR_122: D25.2 (A2), J_Banco_GH1.6, U5.100 (GPIOR_113_CDI22)
/GPIOR_123: D10.2 (A2), J_Banco_GH1.3, U5.99 (GPIOR_116_CTRL15)
/GPIOR_128: D4.2 (A2), J_Banco_I1.7, U5.90 (GPIOR_128_CTRL11)
/GPIOR_129: D19.2 (A2), J_Banco_I1.8, U5.89 (GPIOR_129_CTRL10)
/GPIOR_132: D3.2 (A2), J_Banco_I1.5, U5.87 (GPIOR_132_CDI19)
/GPIOR_133: D17.2 (A2), J_Banco_I1.6, U5.86 (GPIOR_133_CDI18)
/GPIOR_135: D2.2 (A2), J_Banco_I1.3, U5.84 (GPIOR_135_CDI17)
/GPIOR_136: D18.2 (A2), J_Banco_I1.4, U5.83 (GPIOR_136_CDI16)
/GPIOR_138: D1.2 (A2), J_Banco_I1.1, U5.82 (GPIOR_138)
/GPIOR_139: D20.2 (A2), J_Banco_I1.2, U5.81 (GPIOR_139)
/IO: J3.4
/PB4: U2.14 (PC7/HOLD/D3), U5.19 (GPIOL_13_CDI3)
/PB5: U2.15 (PC6/WP/D0), U5.18 (GPIOL_20_CTRL0_CDI4)
/PLLIN0: R5.2, U5.124 (GPIOR_76_PLLIN0), U5.132 (GPIOL_74_PLLIN0), X2.3 (OUT)
/RESET: C10.1, R18.2, S4.3, U2.27 (RESET)
/RESET_T8: C3.1, R1.2, S1.3, U5.35 (~CRESET)
/RX0: J4.1, U2.33 (PE3)
/SDC0_CLK: J1.5 (CLK), R44.1
/SDC0_CMD: J1.3 (CMD), R3.2, U2.10 (PF3/CMD)
/SDC0_D0: J1.7 (DAT0), U2.8 (PF1/D0)
/SDC0_D1: J1.8 (DAT1), U2.7 (PF0/D1)
/SDC0_D2: J1.1 (DAT2), U2.12 (PF5/D2)
/SDC0_D3: J1.2 (CD/DAT3), U2.11 (PF4/D3)
/SDC0_DET: J1.G6 (DET), R40.1, U2.13 (PF6/OWA/IR-RX/PWM5)
/SPI0-CLK: R4.1, U5.3 (GPIOL_53_CDI10)
/SPI0-CS0: U2.18 (PC3/SPI0-CS0/SDC2-CMD), U5.4 (GPIOL_54_CDI11)
/SPI0-MISO: U2.16 (PC5/MISO/D1/SEL1), U5.7 (GPIOL_41_CDI9)
/SPI0-MOSI: U2.17 (PC4/MOSI/D2/SEL0), U5.6 (GPIOL_46)
/TCK: U2.2 (PG7), U5.26 (TCK)
/TDI: U2.1 (PG6), U5.27 (TDI)
/TDO: U2.4 (PG9), U5.24 (TDO)
/TMS: U2.3 (PG8), U5.25 (TMS)
/TX0: J4.2, U2.35 (PE2)
/VCC1V2: C28.2, U5.2 (VCCA_TL), U5.13 (VCC), U5.22 (VCC), U5.49 (VCC), U5.57 (VCC), U5.73 (VCCA_BR), U5.85 (VCC), U5.96 (VCC), U5.107 (VCCA_TR), U5.125 (VCC), U5.128 (VCC), U5.130 (VCC), U8.4 (FB), U8.5 (OUT)
/VCC1V8: C15.2, C23.2, C24.2, C26.1, U1.5 (VOUT), U2.48 (VCC-DRAM0), U2.49 (VCC-DRAM1)
/VCCUSB: C95.1, C96.1, J5.1, J6.2, R2.1, U6.1 (VCC), U7.1 (VIN), U7.3 (EN)
/VCCUSB_SR: J2.2, J3.1
/VCC_RTC: C13.1, C20.1, C25.2, R18.1, U2.20 (VCC-PLL), U2.26 (VCC-RTC), U2.28 (LDOA-OUT), U2.50 (VDD18-DRAM)
/XI: C6.1, U2.23 (DXIN), X1.3 (X2)
/XO: C5.1, U2.22 (DXOUT), X1.1 (X1)
AVDD2V8: C19.2, C21.2, U2.34 (VCC-PE), U3.5 (OUT)
GND: C1.2, C2.2, C3.2, C4.2, C5.2, C6.2, C7.2, C8.2, C9.2, C10.2, C11.2, C12.2, C13.2, C14.1, C15.1, C16.2, C17.1, C19.1, C20.2, C21.1, C22.1, C23.1, C24.1, C25.1, C26.2, C27.2, C28.1, C34.1, C38.1, C39.1, C45.1, C52.1, C56.1, C57.1, C68.1, C95.2, C96.2, D1.1 (A1), D2.1 (A1), D3.1 (A1), D4.1 (A1), D5.1 (A1), D6.1 (A1), D7.1 (A1), D8.1 (A1), D9.1 (A1), D10.1 (A1), D11.1 (A1), D12.1 (A1), D13.1 (A1), D14.1 (A1), D15.1 (A1), D16.1 (A1), D17.1 (A1), D18.1 (A1), D19.1 (A1), D20.1 (A1), D21.1 (A1), D22.1 (A1), D23.1 (A1), D24.1 (A1), D25.1 (A1), D26.1 (A1), D27.1 (A1), D28.1 (A1), D29.1 (A1), D30.1 (A1), D31.1 (A1), D32.1 (A1), J1.6 (VSS), J1.G1 (GND), J1.G2 (GND), J1.G3 (GND), J1.G4 (GND), J1.G5 (GND), J2.1, J3.5, J5.2, J6.1, J_Banco_E1.9, J_Banco_F1.9, J_Banco_GH1.9, J_Banco_I1.9, R5.1, R6.2, R75.2, S1.1, S4.1, U1.2 (GND), U2.129 (EPAD), U3.2 (GND), U3.4 (GND), U4.2 (GND), U5.1 (GND), U5.5 (GND), U5.9 (GND), U5.37 (GND), U5.44 (GND), U5.50 (GND), U5.64 (GND), U5.94 (GND), U5.104 (GND), U5.108 (GND), U5.120 (GND), U5.121 (GND), U5.126 (GND), U5.127 (GND), U5.129 (GND), U5.133 (GND), U6.2 (GND), U7.2 (GND), U8.2 (GND), X1.2 (NC1), X1.4 (NC2), X2.2 (GND)
unnamed: DS3.2, R75.1
unnamed: R7.2, U1.4 (PG)
unnamed: R6.1, U2.47 (DZQ)
unnamed: C12.1, U2.30 (LDOB-OUT)
unnamed: R4.2, U2.19 (PC2/SPI0-CLK/SDC2-CLK)
unnamed: R44.2, U2.9 (PF2/CLK)
unnamed: R2.2, U7.4 (PG)
VCC3V3: C2.1, C7.1, C11.1, C14.2, C16.1, C22.2, C34.2, C38.2, C39.2, DS3.1, J1.4 (VDD), J_Banco_E1.10, J_Banco_F1.10, J_Banco_GH1.10, J_Banco_I1.10, R1.1, R3.1, R8.2, R9.2, R10.2, R40.2, U2.29 (LDO-IN), U2.83 (VCC-IO), U2.128 (VCC-PG), U6.3 (EN), U7.5 (VOUT), X2.1 (EN), X2.4 (Vdd)
VCC-CORE: C4.1, C45.2, C52.2, C56.2, C57.2, C68.2, U2.46 (VDD-SYS0), U2.51 (VDD-SYS1), U2.81 (VDD-SYS2), U2.116 (VDD-CORE0), U2.117 (VDD-CORE1), U4.5 (VOUT)

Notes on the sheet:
t=0s ==================================================================================================> t(s)
OSCILADOR 25MHz
Vcc_IO=3.3V
1.8V/1.5V/1.35@0.4A
Circuito de Reinicio T8 Basado en T8F81
TWI2
Default 1.35V
3.3V
GPIO de la FPGA T8
T8Q144C3
Cshunt = 6.5pF
2.8V
RX5-T8
CORE 0.9V
SEL[1:0] 00: NOR > NAND 01: SD > NOR > Other √10: SD > NAND > Other 11 SD0 > EMMC2 > EMMC2_USR >Other
TPADC GPADC
USB
Basado en la tarjeta de desarrollo de Efinix Inc. T8F81
1.8V
TX5-T8
Cshunt = 1.1pF
1.2V
Vcore=1.2V
POTENCIA
Circuito de Reinicio F133
Salida de Alimentación
1.8V@0.26A
TX5-F133A
RX5-F133A
Control desde PC
1A (NO: 24,25,26,27,34,35) =6 1B =7 ----- 1C =4 1D =3 ----- 1E =12 3A =12 ----- 3B =4 3C =6 ----- 3D =9 3E =7 ----- 4A =13 4B (NO 36) =11 -----
BANCOS DE GPIO: Pines 113-119, 123 (F) Pines 93, 97-101(H); 102-103 (G) Pines 136-142, 144 (E) Pines 81-84, 86, 87, 89, 90 (I)

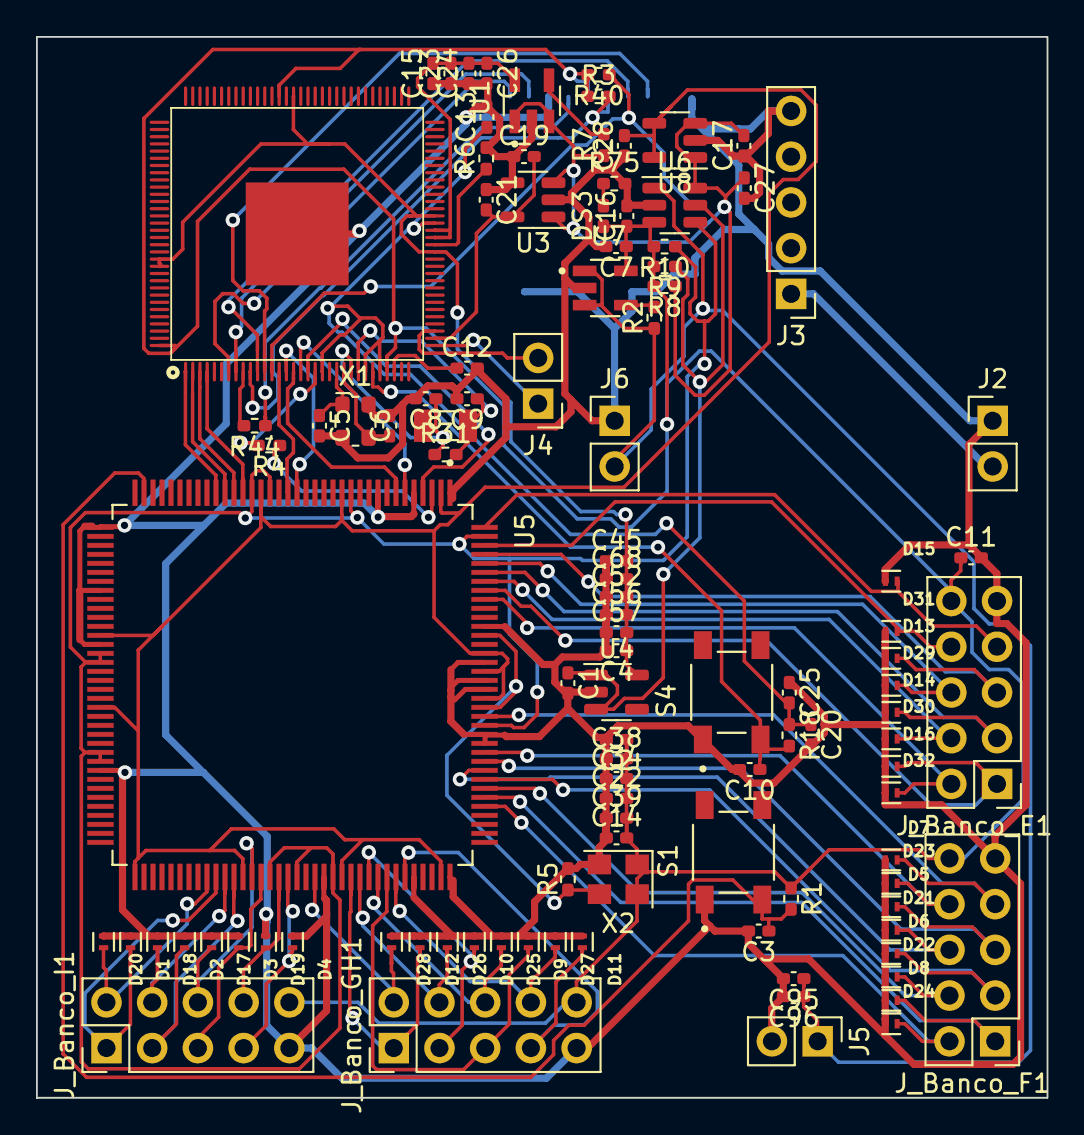
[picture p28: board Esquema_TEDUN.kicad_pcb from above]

Board: 2 copper layers, 56.1 x 58.9 mm, 108 parts (1 on the bottom side), 77 nets.
